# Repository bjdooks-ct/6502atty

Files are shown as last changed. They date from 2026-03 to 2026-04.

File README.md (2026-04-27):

# 6502 Atty

A 6502 SBC with an ATMega as a contoller and monitor for the 6502.

This is an initial commit as PCBs are off for manufacture and not been tested. This includes the prototype firmware and the first cut of the firmware code.

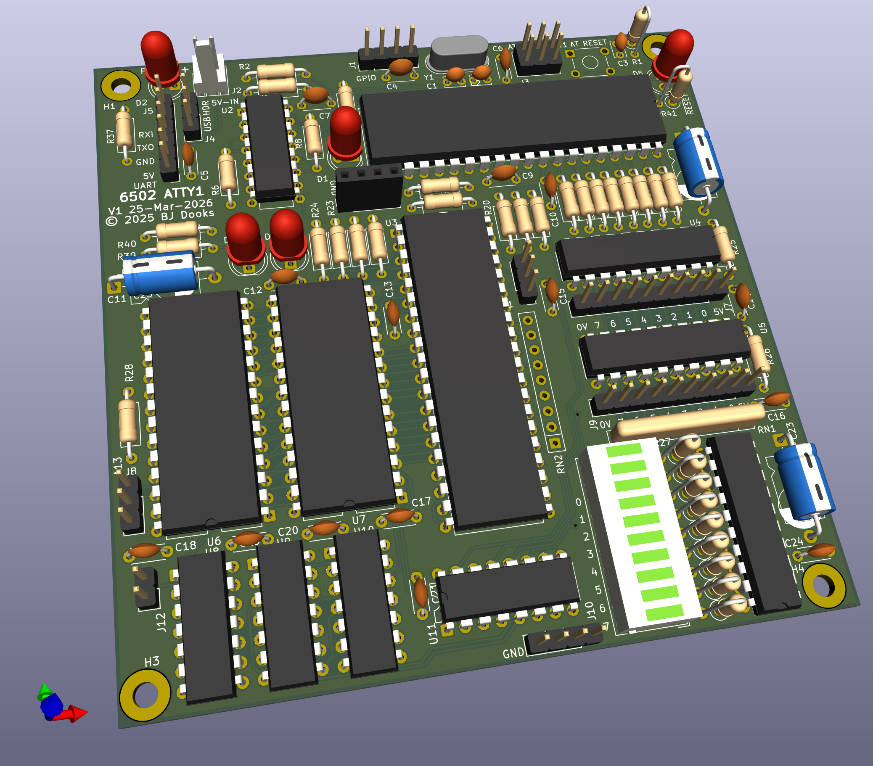
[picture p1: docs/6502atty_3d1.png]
3D PCB view


The ATmega is probably the easiest MCU to get and program which is 5V tolerant. The 1284P is the current choice as the smaller memory versions are not much cheaper.

There is now a [photo album](https://photos.app.goo.gl/qwDDgCh3WiyMoqd4A) of the build on my google photos.

The clock synchronisation logic is provided by U2A and U2B. U2B takes the PWM output from the ATMega and is used to both halve ti and make it a square wave. The /S input is used when the clock is high to stop any transition low (which would complete the 6502's cycle) which comes from the U2A flip-flop. U2A is triggered by an access to the ATMega and sets /CLOCK_STOP active to stop the 6502 clock until the /AT_ACK signal is active, resetting U2A and making /CLOCK_STOP inactive which then allows U2B to continue generating a clock for the 6502.

## Build notes for v1 rev1

- The 100UF capacitors are 16mm long so trying 47uF, layout change?

The LED resistors will probably need to be reduced to 680R or low as 506R depending on the LEDs being fitted.

The pull-up/pull-down resistors can be anywhere from 1K to 4K7, experiments with previous boards show 10K may not be suitable with certain variants of the 6052. Anything below 1K is probably going to have issues with current dissapation as that will be around 5mA per resistor. 

During test it was found that there seems to be a difference in operation dependong on how the PHi2 jumper is selected. If the PHI2O is used, we get proper operation but if CPU_CLK is seleted then the download code works but the code that is downloaded does not work.

## PCB updates (v1 rev2)

The updates for the second PCB revision are mostly bug-fixes and to make the board smaller to try and get to the 10x10cm point that JLCPCB and others use for cheaper services. There may be in future a version with a few bits of surface mount, like moving to one of the USB capable Atmel devices and adding a direct USB port.

- Added J12 to route ~WE signal to the PGM/~WE to allow SRAM
  - Also requires a R/!W signal gated with PHI2 high
  - Added R~{W}ph signal for ROM
  - This new signal could also drive RAM ~WE and connect ~CS to A15
- Connected ROM's VPP signal to GND, if using SRAM, ties A14 to GND
- U9C's pins 9 and 10 swapped for routing
- U11's E1/E2 pins swapped for easier routing
- Transcription error from prototype, ROM_ACC should be from AND not NAND gate
  - Swao U8C for one of U10 spare gates
- RDY line missing pull-up resistor
- 74LS573 replaced with 74LS574
  - 573 latches when Load is high, and our enable is low
  - 574 will load on rising edge of load pin, so should work
- Made PCB smaller, moved a few LEDs and things around to make this work
- Dropped 1K series drive resistor for the crystal
  - ATMega will not start if this resistor is there
- Serial converter is rotated 180deg to the actual unit
- Recomendation for AVRisp is to use 10K on ATMega's nRESET, so changed for now
  - See crystal series resistor notes.
- Added silkscreen with major part info to help with production

Currently unknown issues:
- Firmware only works with PHI2 jumper on PHI2out
  - can't see any scoped difference between CPUclk and PHI2out
  - possibly a rise-time on the clock with the 1K resistor in it

## PCB updates (v1 rev3)

This revision has minor updates for ease of assembly and a few minor annoyances over how the layout has come out, such as the mounting hole positions not being fully aligned.

The changes are:

- Made LEDs all the same orientation
  - also changed D2's resistor to be on ground side to make routing nicer
- Reduction in the x-size of the board by pushing control logic over
- Changed ROM A13 to solder pad, probably ok to just have A13 on this pin
- Used per-pin options on DIP to remove automatic ground ties
  - manually added a single ground tie to those pads
  - also made the keep-out a bit bigger to allow easier isolation cuts
- Made hole positions mostly consistent at edge of board
- Got down to 100x100mm dimensions with a more shuffling
- Added header and resistors for last two LEDs on bargrapth
  - Hesader J13 and two resistors to VCC for these
- Replaced input buffer U5 with 74x574
  - Added IOCLK from PHI2
  - Removed R26 as not needed
- could we use a 74x574 as input buffer too
  - if we tied ~OE and CP this would almost work, FF loaded on low-high
  - decided to bring PHI2 to the 74x574 to load state before read
  - device latches on low high and we need stable during the high clock phase
- Minor updats to clearand and island removal on the power planes

Processed the files and sent to JLCPCB, the manufacturing files commited in kicad/release3

To do for rev4:
- do we really need to have pull-ups on nmi/irq lines
  - atmega is always going to be needed unless you inject clk into gates

# Firmware

The firmware is currently in development. To build, you will need at-least avr-gcc and the relevant libraries and is currently only being tested on Linux (Debian). Once built, download to the ATMega using something like avrdude.

## Revision information

The original prototype version was built on a perfboard, and not released.

# Notes

Bee logo provided by Rob Kendrick

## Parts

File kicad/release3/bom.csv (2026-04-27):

Designator | Footprint | Quantity | Value | LCSC Part #
BAR1 | HDSP-4850 | 1 | HDSP-4850
C1, C2 | C_Disc_D3.4mm_W2.1mm_P2.50mm | 2 | 12pF
C10 | C_Disc_D4.3mm_W1.9mm_P5.00mm | 1 | ~
C11, C23, C8 | CP_Axial_L10.0mm_D6.0mm_P15.00mm_Horizontal | 3 | 100uF/16V
C12, C13, C14, C15, C16, C17, C18, C19, C20, C21, C24, C4, C5, C6, C7, C9 | C_Disc_D4.3mm_W1.9mm_P5.00mm | 16 | 100nF
C3 | C_Disc_D3.4mm_W2.1mm_P2.50mm | 1 | ?
D1 | LED_D5.0mm | 1 | LED_Small_Filled
D2, D3, D4, D5 | LED_D5.0mm | 4 | RED
J1, J10 | PinHeader_1x04_P2.54mm_Vertical | 2 | Conn_01x04_Pin
J11, J4 | PinHeader_1x03_P2.54mm_Vertical | 2 | Conn_01x03_Pin
J12, J13 | PinHeader_1x02_P2.54mm_Vertical | 2 | Conn_01x02_Pin
J2 | Molex_KK-254_AE-6410-02A_1x02_P2.54mm_Vertical | 1 | Conn_01x02_Pin
J3 | PinHeader_2x03_P2.54mm_Vertical | 1 | Conn_02x03_Odd_Even
J5 | PinHeader_1x06_P2.54mm_Vertical | 1 | Conn_01x06_Pin
J6 | PinSocket_1x04_P2.54mm_Vertical | 1 | Conn_01x04_Pin
J7, J9 | PinHeader_1x10_P2.54mm_Vertical | 2 | Conn_01x10_Pin
R1 | R_Axial_DIN0207_L6.3mm_D2.5mm_P2.54mm_Vertical | 1 | 10K
R10, R11, R12, R13, R14, R15, R16, R17 | R_Axial_DIN0207_L6.3mm_D2.5mm_P10.16mm_Horizontal | 8 | 330R
R18, R19, R20, R21, R22, R23, R25, R28, R6, R8, R9 | R_Axial_DIN0207_L6.3mm_D2.5mm_P10.16mm_Horizontal | 11 | 4K7
R2, R3, R37, R39, R40 | R_Axial_DIN0207_L6.3mm_D2.5mm_P10.16mm_Horizontal | 5 | 1K
R24 | R_Axial_DIN0207_L6.3mm_D2.5mm_P10.16mm_Horizontal | 1 | 560R
R27, R29, R30, R31, R32, R33, R34, R35, R36, R38 | R_Axial_DIN0207_L6.3mm_D2.5mm_P2.54mm_Vertical | 10 | 680R
R41, R5 | R_Axial_DIN0207_L6.3mm_D2.5mm_P2.54mm_Vertical | 2 | 1K
R42 | R_Axial_DIN0207_L6.3mm_D2.5mm_P10.16mm_Horizontal | 1 | R
RN1 | R_Array_SIP9 | 1 | 4K7
SW1 | SW_TH_Tactile_Omron_B3F-10xx | 1 | SW_Push
U1 | DIP-40_W15.24mm | 1 | ATmega164P-20P
U10 | DIP-14_W7.62mm | 1 | 74LS08
U11 | DIP-16_W7.62mm | 1 | 74LS138
U12, U13, U4 | DIP-20_W7.62mm | 3 | 74LS574
U2 | DIP-16_W7.62mm | 1 | 74LS112
U3 | DIP-40_W15.24mm | 1 | W65C02SxP
U6 | DIP-28_W15.24mm | 1 | 27C128
U7 | DIP-28_W15.24mm | 1 | KM62256CLP
U8, U9 | DIP-14_W7.62mm | 2 | 74LS00
Y1 | Crystal_HC49-4H_Vertical | 1 | 18.432MHz

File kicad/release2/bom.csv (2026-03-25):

Designator | Footprint | Quantity | Value | LCSC Part #
BAR1 | HDSP-4850 | 1 | HDSP-4850
C1, C2 | C_Disc_D3.4mm_W2.1mm_P2.50mm | 2 | 12pF
C10 | C_Disc_D4.3mm_W1.9mm_P5.00mm | 1 | ~
C11, C23, C8 | CP_Axial_L10.0mm_D6.0mm_P15.00mm_Horizontal | 3 | 100uF/16V
C12, C13, C14, C15, C16, C17, C18, C19, C20, C21, C24, C4, C5, C6, C7, C9 | C_Disc_D4.3mm_W1.9mm_P5.00mm | 16 | 100nF
C3 | C_Disc_D3.4mm_W2.1mm_P2.50mm | 1 | ?
D1 | LED_D5.0mm | 1 | LED_Small_Filled
D2, D3, D4, D5 | LED_D5.0mm | 4 | RED
J1, J10 | PinHeader_1x04_P2.54mm_Vertical | 2 | Conn_01x04_Pin
J11, J4, J8 | PinHeader_1x03_P2.54mm_Vertical | 3 | Conn_01x03_Pin
J12 | PinHeader_1x02_P2.54mm_Vertical | 1 | Conn_01x02_Pin
J2 | Molex_KK-254_AE-6410-02A_1x02_P2.54mm_Vertical | 1 | Conn_01x02_Pin
J3 | PinHeader_2x03_P2.54mm_Vertical | 1 | Conn_02x03_Odd_Even
J5 | PinHeader_1x06_P2.54mm_Vertical | 1 | Conn_01x06_Pin
J6 | PinSocket_1x04_P2.54mm_Vertical | 1 | Conn_01x04_Pin
J7, J9 | PinHeader_1x10_P2.54mm_Vertical | 2 | Conn_01x10_Pin
R1 | R_Axial_DIN0207_L6.3mm_D2.5mm_P2.54mm_Vertical | 1 | 10K
R10, R11, R12, R13, R14, R15, R16, R17 | R_Axial_DIN0207_L6.3mm_D2.5mm_P10.16mm_Horizontal | 8 | 330R
R18, R19, R20, R21, R22, R23, R25, R26, R28, R6, R8, R9 | R_Axial_DIN0207_L6.3mm_D2.5mm_P10.16mm_Horizontal | 12 | 4K7
R2, R3, R37, R39, R40, R5 | R_Axial_DIN0207_L6.3mm_D2.5mm_P10.16mm_Horizontal | 6 | 1K
R24 | R_Axial_DIN0207_L6.3mm_D2.5mm_P10.16mm_Horizontal | 1 | 560R
R27, R29, R30, R31, R32, R33, R34, R35, R38 | R_Axial_DIN0207_L6.3mm_D2.5mm_P2.54mm_Vertical | 9 | 680R
R41 | R_Axial_DIN0207_L6.3mm_D2.5mm_P2.54mm_Vertical | 1 | 1K
R42 | R_Axial_DIN0207_L6.3mm_D2.5mm_P10.16mm_Horizontal | 1 | R
RN1 | R_Array_SIP9 | 1 | R_Network08
SW1 | SW_TH_Tactile_Omron_B3F-10xx | 1 | SW_Push
U1 | DIP-40_W15.24mm | 1 | ATmega164P-20P
U10 | DIP-14_W7.62mm | 1 | 74LS08
U11 | DIP-16_W7.62mm | 1 | 74LS138
U12, U4 | DIP-20_W7.62mm | 2 | 74LS574
U2 | DIP-16_W7.62mm | 1 | 74LS112
U3 | DIP-40_W15.24mm | 1 | W65C02SxP
U5 | DIP-20_W7.62mm | 1 | 74HC245
U6 | DIP-28_W15.24mm | 1 | 27C128
U7 | DIP-28_W15.24mm | 1 | KM62256CLP
U8, U9 | DIP-14_W7.62mm | 2 | 74LS00
Y1 | Crystal_HC49-4H_Vertical | 1 | 18.432MHz

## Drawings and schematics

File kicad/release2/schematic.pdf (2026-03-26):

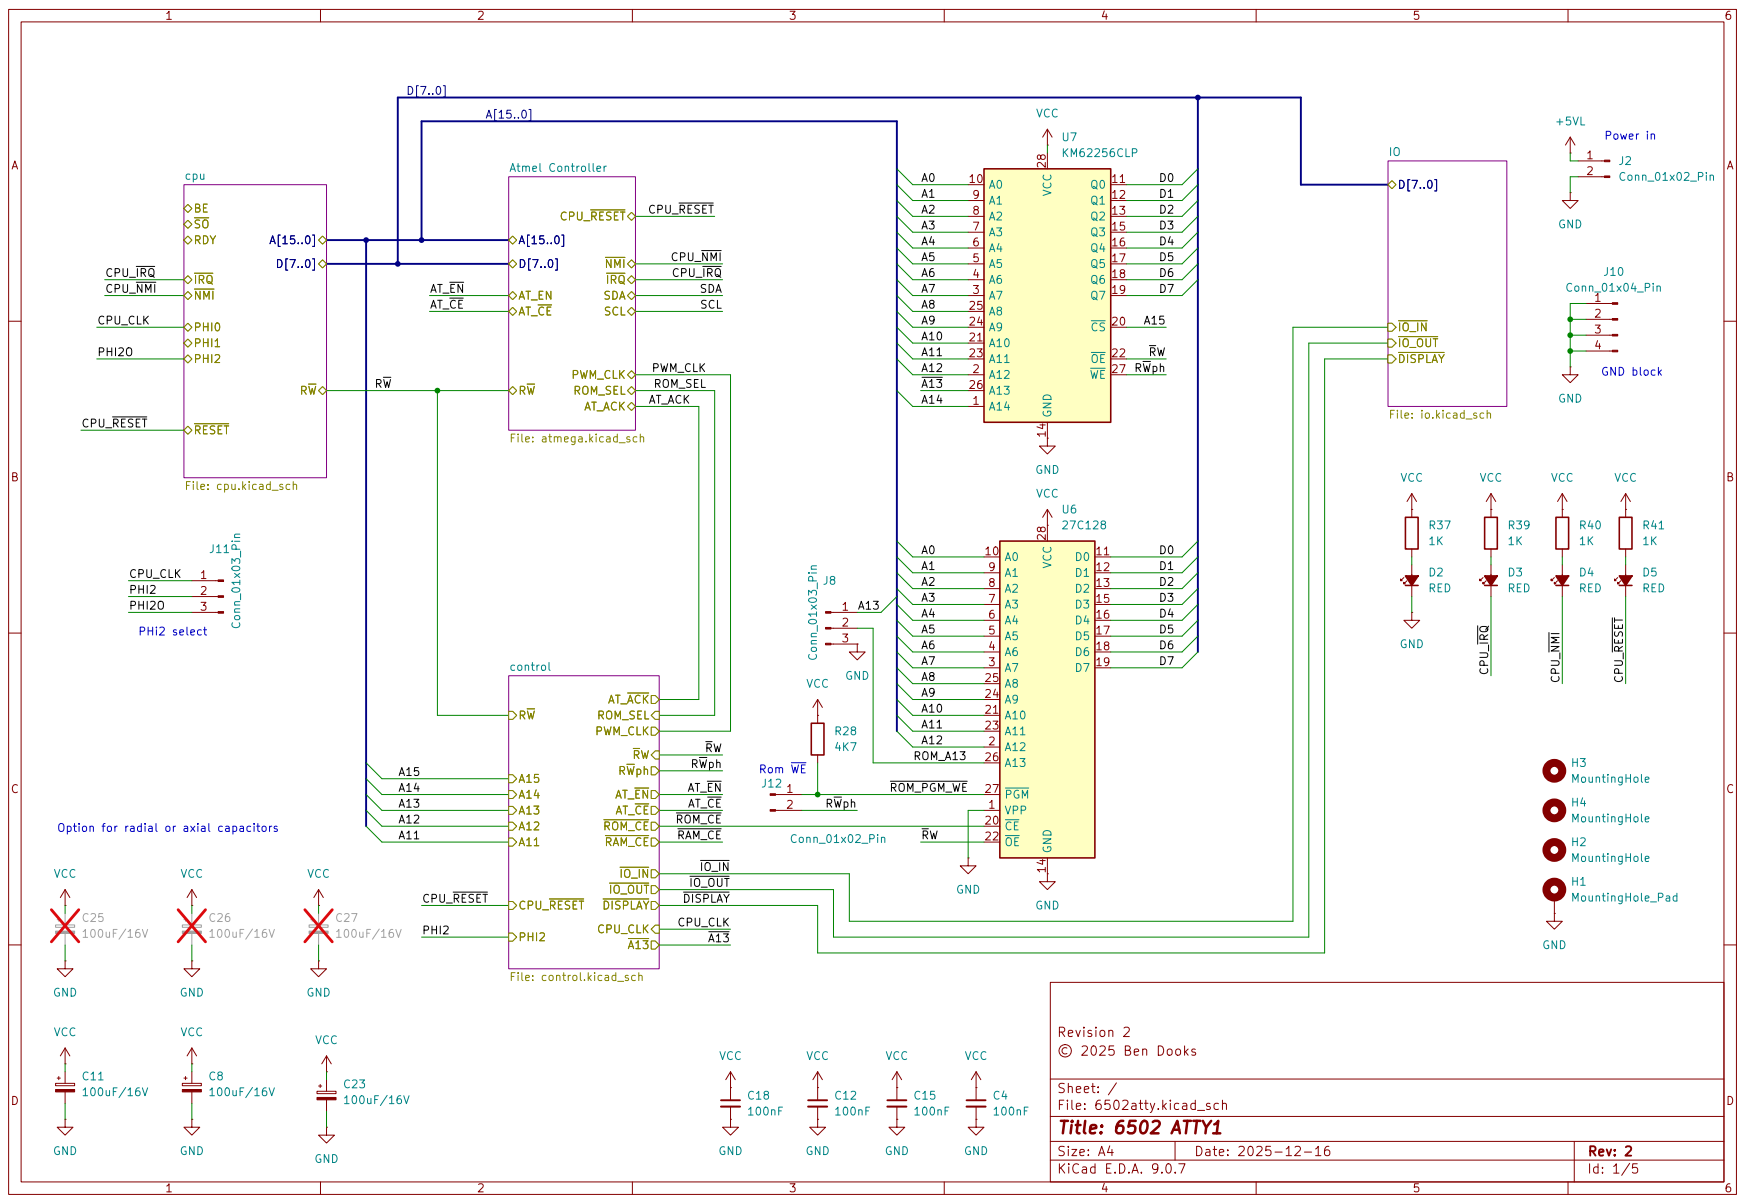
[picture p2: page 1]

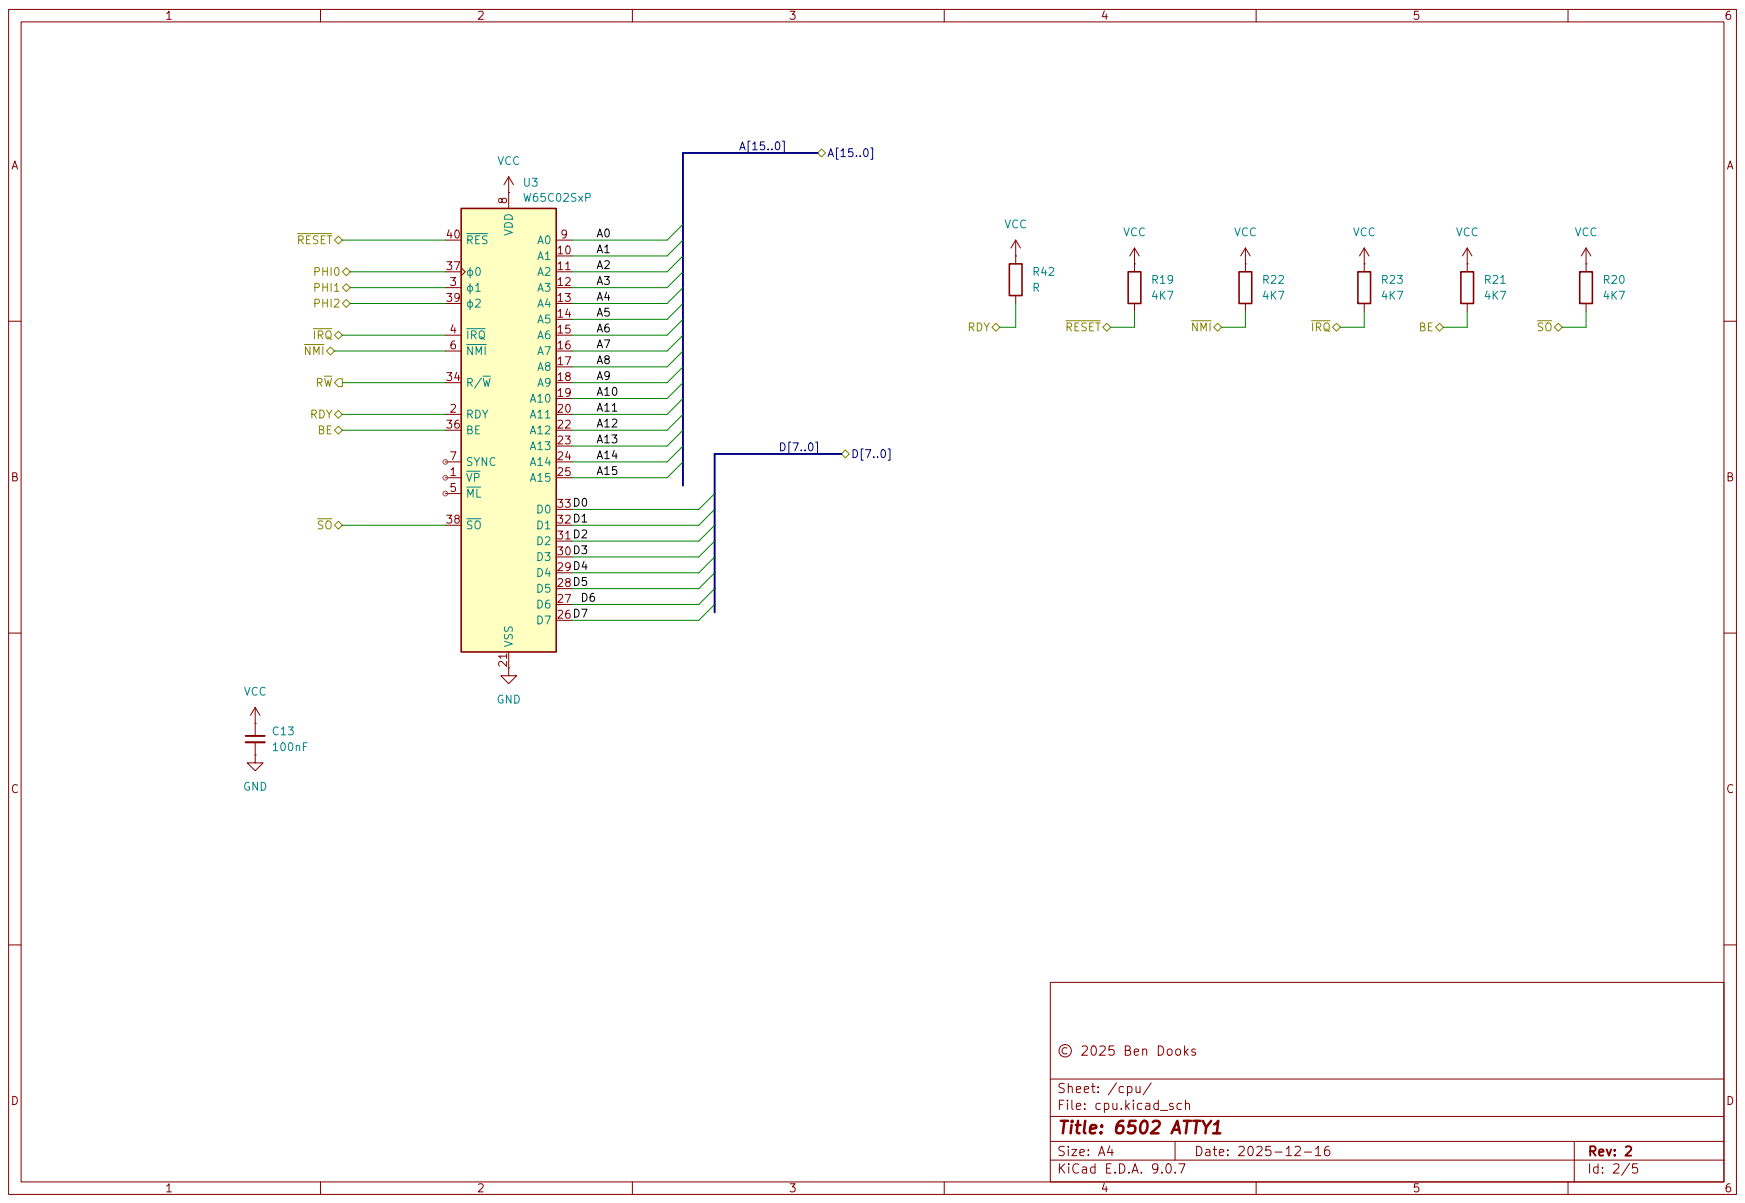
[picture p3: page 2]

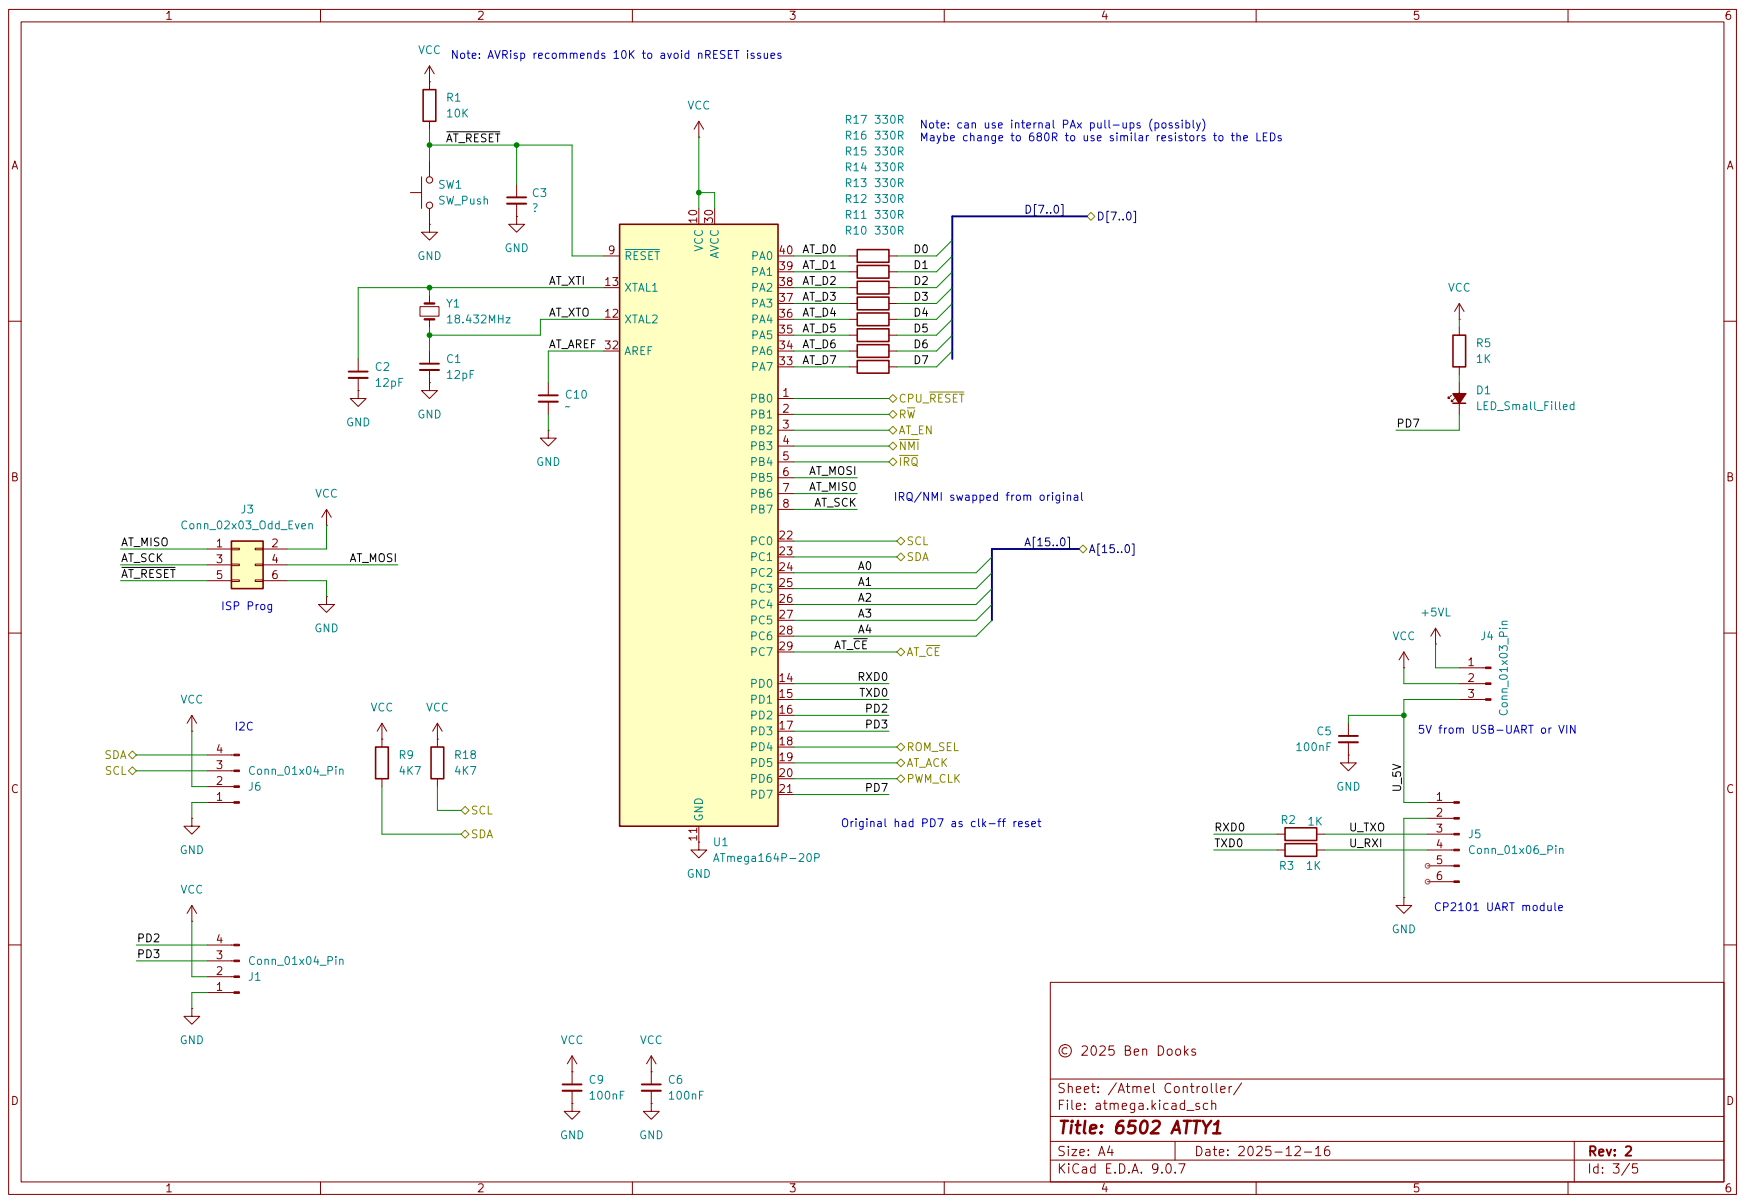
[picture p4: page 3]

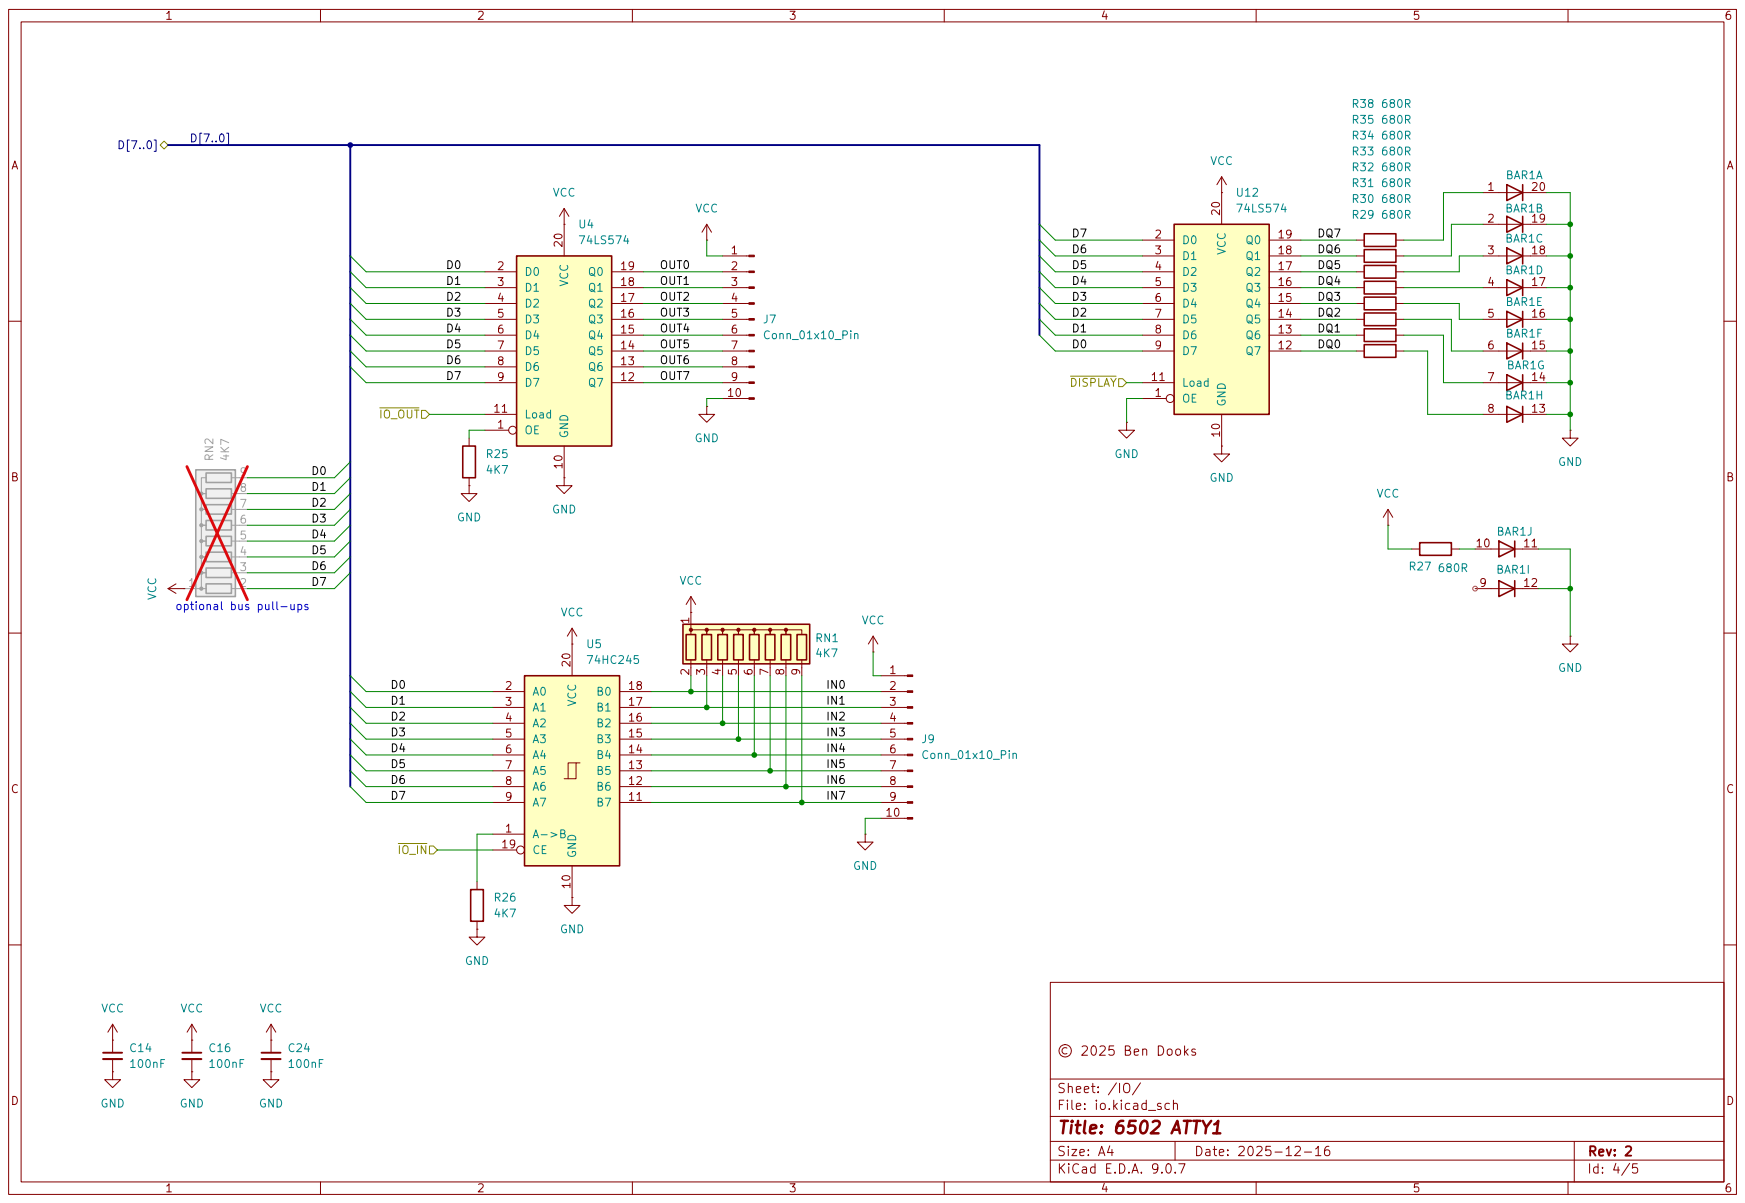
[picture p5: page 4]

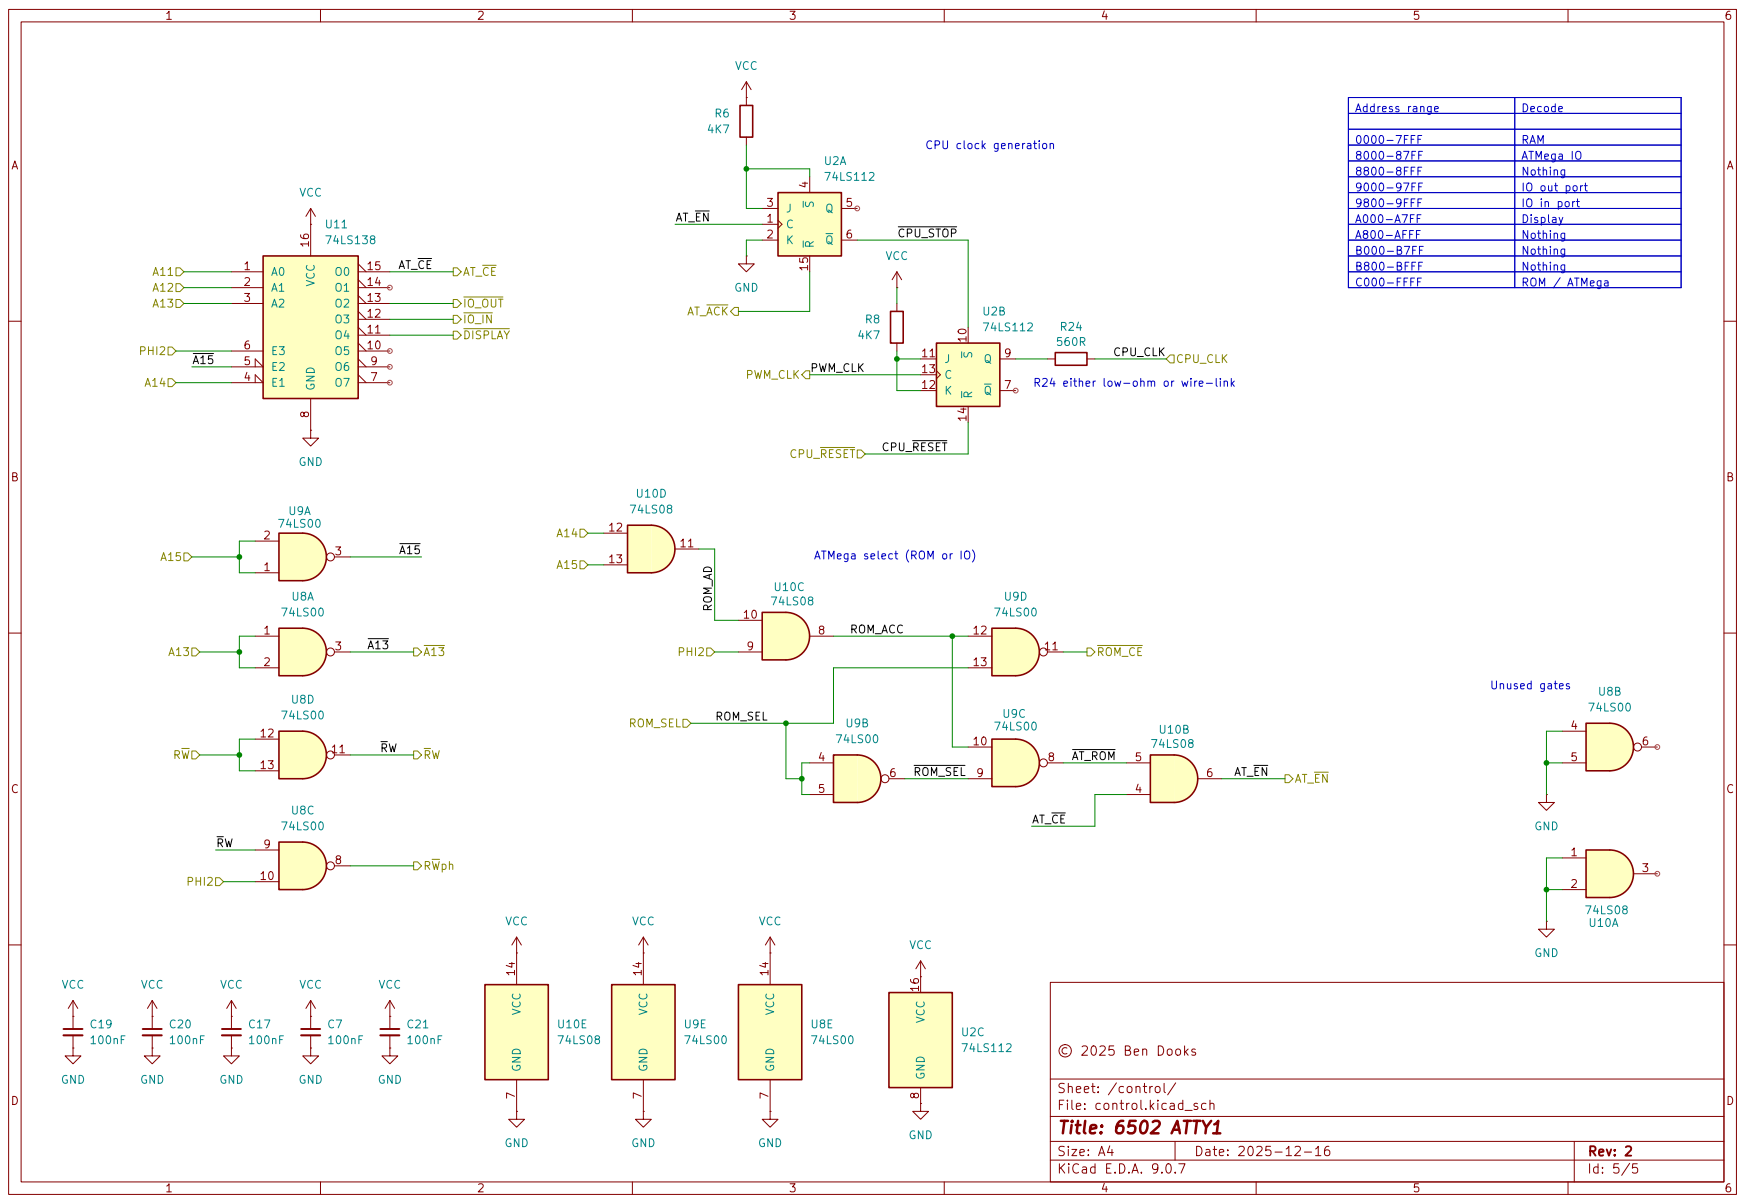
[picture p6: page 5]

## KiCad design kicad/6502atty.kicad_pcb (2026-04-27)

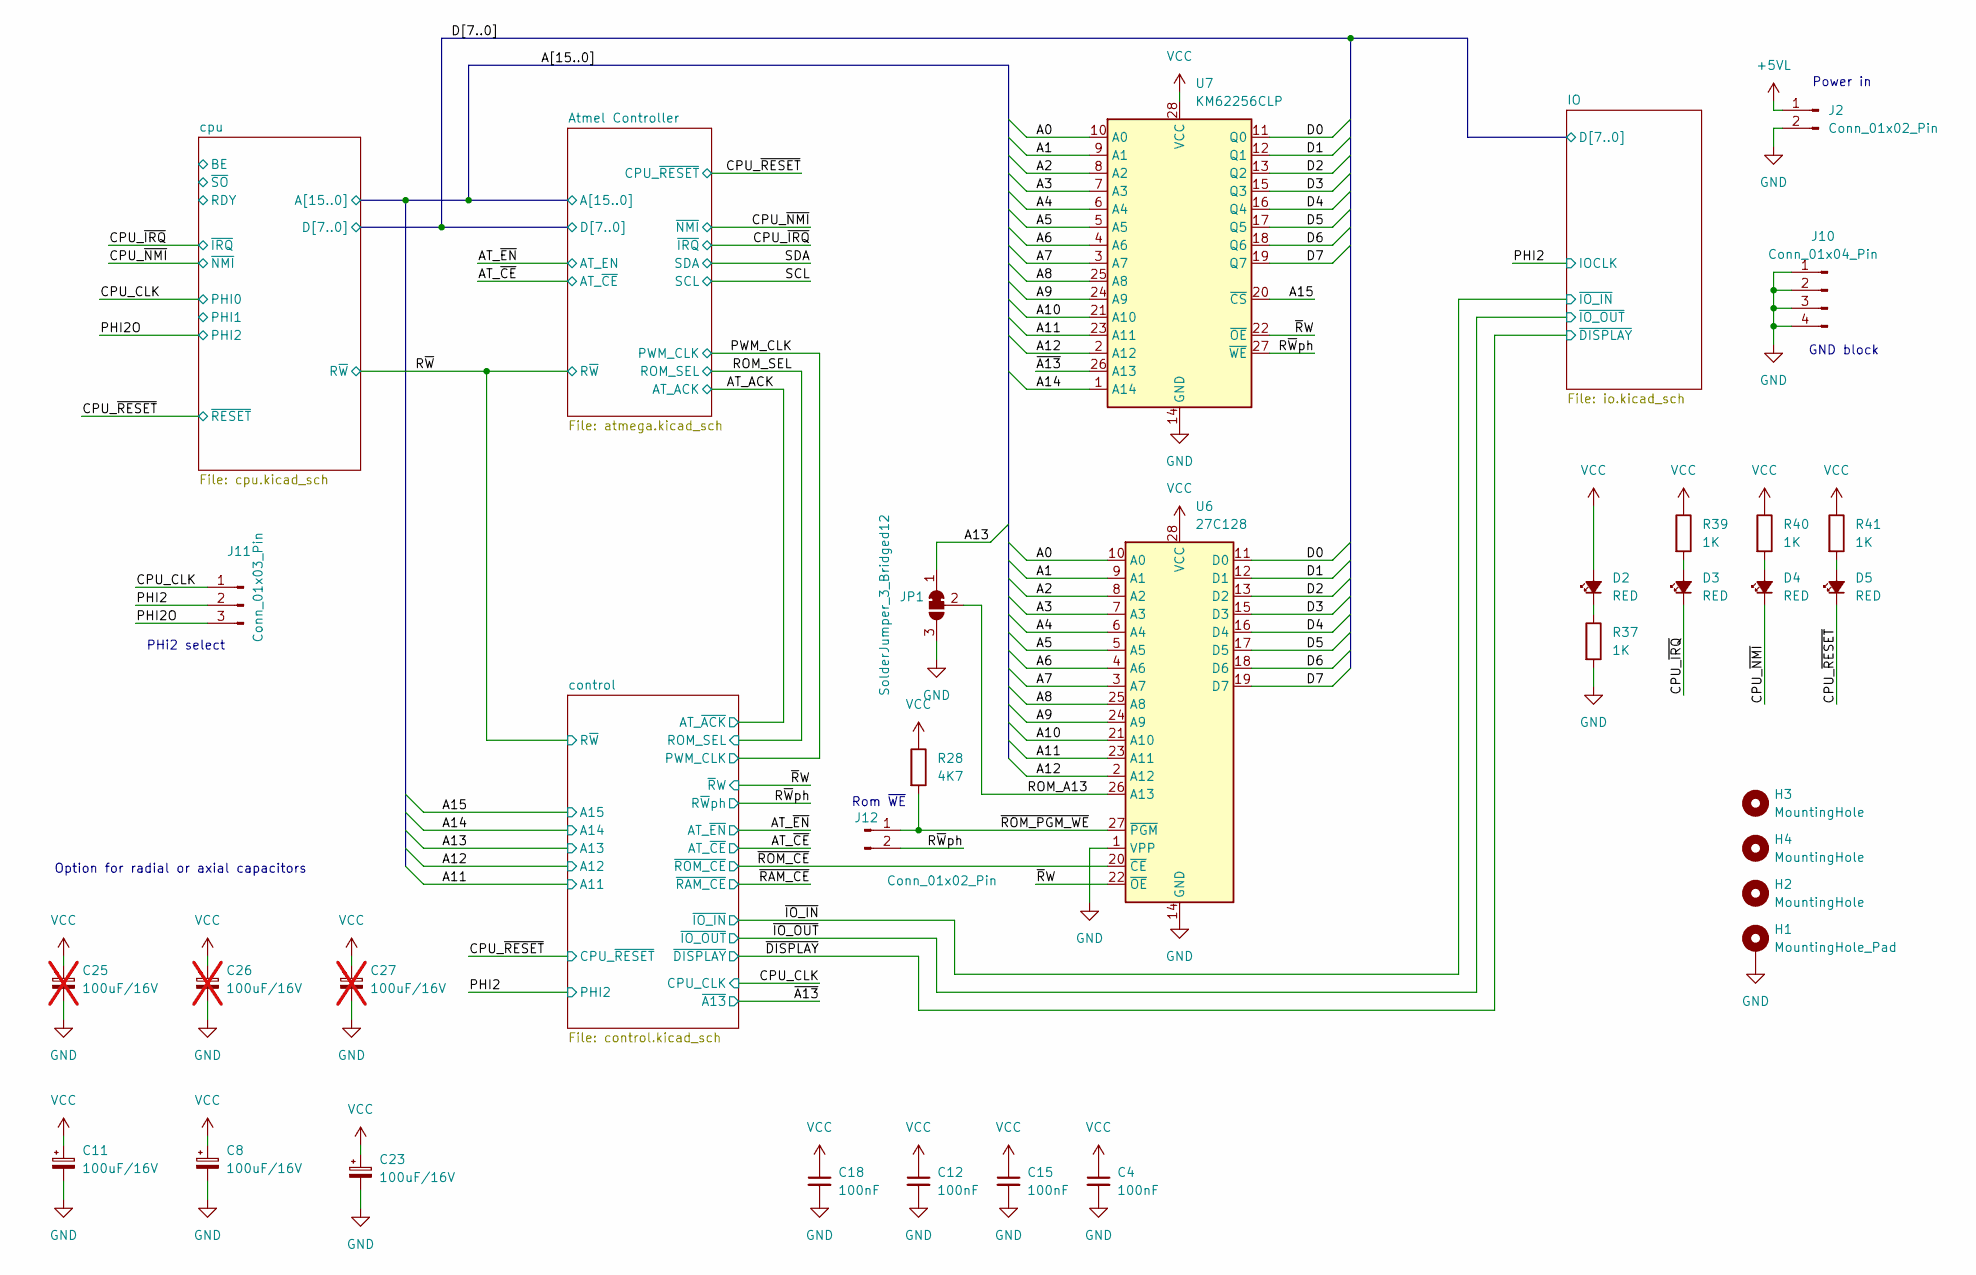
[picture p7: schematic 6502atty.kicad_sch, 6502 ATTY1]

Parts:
C4, C12, C15, C18: 100nF; C_Disc_D4.3mm_W1.9mm_P5.00mm
C8, C11, C23: 100uF/16V; CP_Axial_L10.0mm_D6.0mm_P15.00mm_Horizontal
C25, C26, C27: 100uF/16V; CP_Radial_D6.3mm_P2.50mm; not fitted
D2, D3, D4, D5: RED; LED_D5.0mm
H1: MountingHole_Pad; MountingHole_3.2mm_M3_Pad
H2, H3, H4: MountingHole; MountingHole_3.2mm_M3_Pad
J2: Conn_01x02_Pin; Molex_KK-254_AE-6410-02A_1x02_P2.54mm_Vertical
J10: Conn_01x04_Pin; PinHeader_1x04_P2.54mm_Vertical
J11: Conn_01x03_Pin; PinHeader_1x03_P2.54mm_Vertical
J12: Conn_01x02_Pin; PinHeader_1x02_P2.54mm_Vertical
JP1: SolderJumper_3_Bridged12; SolderJumper-3_P1.3mm_Bridged12_Pad1.0x1.5mm_NumberLabels
R28: 4K7; R_Axial_DIN0207_L6.3mm_D2.5mm_P10.16mm_Horizontal
R37, R39, R40: 1K; R_Axial_DIN0207_L6.3mm_D2.5mm_P10.16mm_Horizontal
R41: 1K; R_Axial_DIN0207_L6.3mm_D2.5mm_P2.54mm_Vertical
U6: 27C128; DIP-28_W15.24mm
U7: KM62256CLP; DIP-28_W15.24mm

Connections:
+5VL: J2.1; also elsewhere on the board
/A0: U6.10 (A0), U7.10 (A0); also elsewhere on the board
/A1: U6.9 (A1), U7.9 (A1); also elsewhere on the board
/A2: U6.8 (A2), U7.8 (A2); also elsewhere on the board
/A3: U6.7 (A3), U7.7 (A3); also elsewhere on the board
/A4: U6.6 (A4), U7.6 (A4); also elsewhere on the board
/A5: U6.5 (A5), U7.5 (A5); also elsewhere on the board
/A6: U6.4 (A6), U7.4 (A6); also elsewhere on the board
/A7: U6.3 (A7), U7.3 (A7); also elsewhere on the board
/A8: U6.25 (A8), U7.25 (A8); also elsewhere on the board
/A9: U6.24 (A9), U7.24 (A9); also elsewhere on the board
/A10: U6.21 (A10), U7.21 (A10); also elsewhere on the board
/A11: U6.23 (A11), U7.23 (A11); also elsewhere on the board
/A12: U6.2 (A12), U7.2 (A12); also elsewhere on the board
/A13: JP1.1 (A); also elsewhere on the board
/A14: U7.1 (A14); also elsewhere on the board
/A15: U7.20 (~CS); also elsewhere on the board
/CPU_CLK: J11.1; also elsewhere on the board
/CPU_~IRQ: D3.1 (K); also elsewhere on the board
/CPU_~NMI: D4.1 (K); also elsewhere on the board
/CPU_~RESET: D5.1 (K); also elsewhere on the board
/D0: U6.11 (D0), U7.11 (Q0); also elsewhere on the board
/D1: U6.12 (D1), U7.12 (Q1); also elsewhere on the board
/D2: U6.13 (D2), U7.13 (Q2); also elsewhere on the board
/D3: U6.15 (D3), U7.15 (Q3); also elsewhere on the board
/D4: U6.16 (D4), U7.16 (Q4); also elsewhere on the board
/D5: U6.17 (D5), U7.17 (Q5); also elsewhere on the board
/D6: U6.18 (D6), U7.18 (Q6); also elsewhere on the board
/D7: U6.19 (D7), U7.19 (Q7); also elsewhere on the board
/PHI2: J11.2; also elsewhere on the board
/PHI2O: J11.3; also elsewhere on the board
/ROM_A13: JP1.2 (C), U6.26 (A13)
/R~Wph: J12.2, U7.27 (~WE); also elsewhere on the board
/~A13: U7.26 (A13); also elsewhere on the board
/~ROM_CE: U6.20 (~CE); also elsewhere on the board
/~ROM_PGM_WE: J12.1, R28.2, U6.27 (~PGM)
/~RW: U6.22 (~OE), U7.22 (~OE); also elsewhere on the board
GND: C4.2, C8.2, C11.2, C12.2, C15.2, C18.2, C23.2, C25.2, C26.2, C27.2, H1.1 (1_1), J2.2, J10.1, J10.2, J10.3, J10.4, JP1.3 (B), R37.2, U6.1 (VPP), U6.14 (GND), U7.14 (GND); also elsewhere on the board
unnamed: D2.1 (K), R37.1
unnamed: D3.2 (A), R39.2
unnamed: D4.2 (A), R40.2
unnamed: D5.2 (A), R41.2
VCC: C4.1, C8.1, C11.1, C12.1, C15.1, C18.1, C23.1, C25.1, C26.1, C27.1, D2.2 (A), R28.1, R39.1, R40.1, R41.1, U6.28 (VCC), U7.28 (VCC); also elsewhere on the board

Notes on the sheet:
Power in
GND block
Option for radial or axial capacitors
PHi2 select
Rom ~{WE}

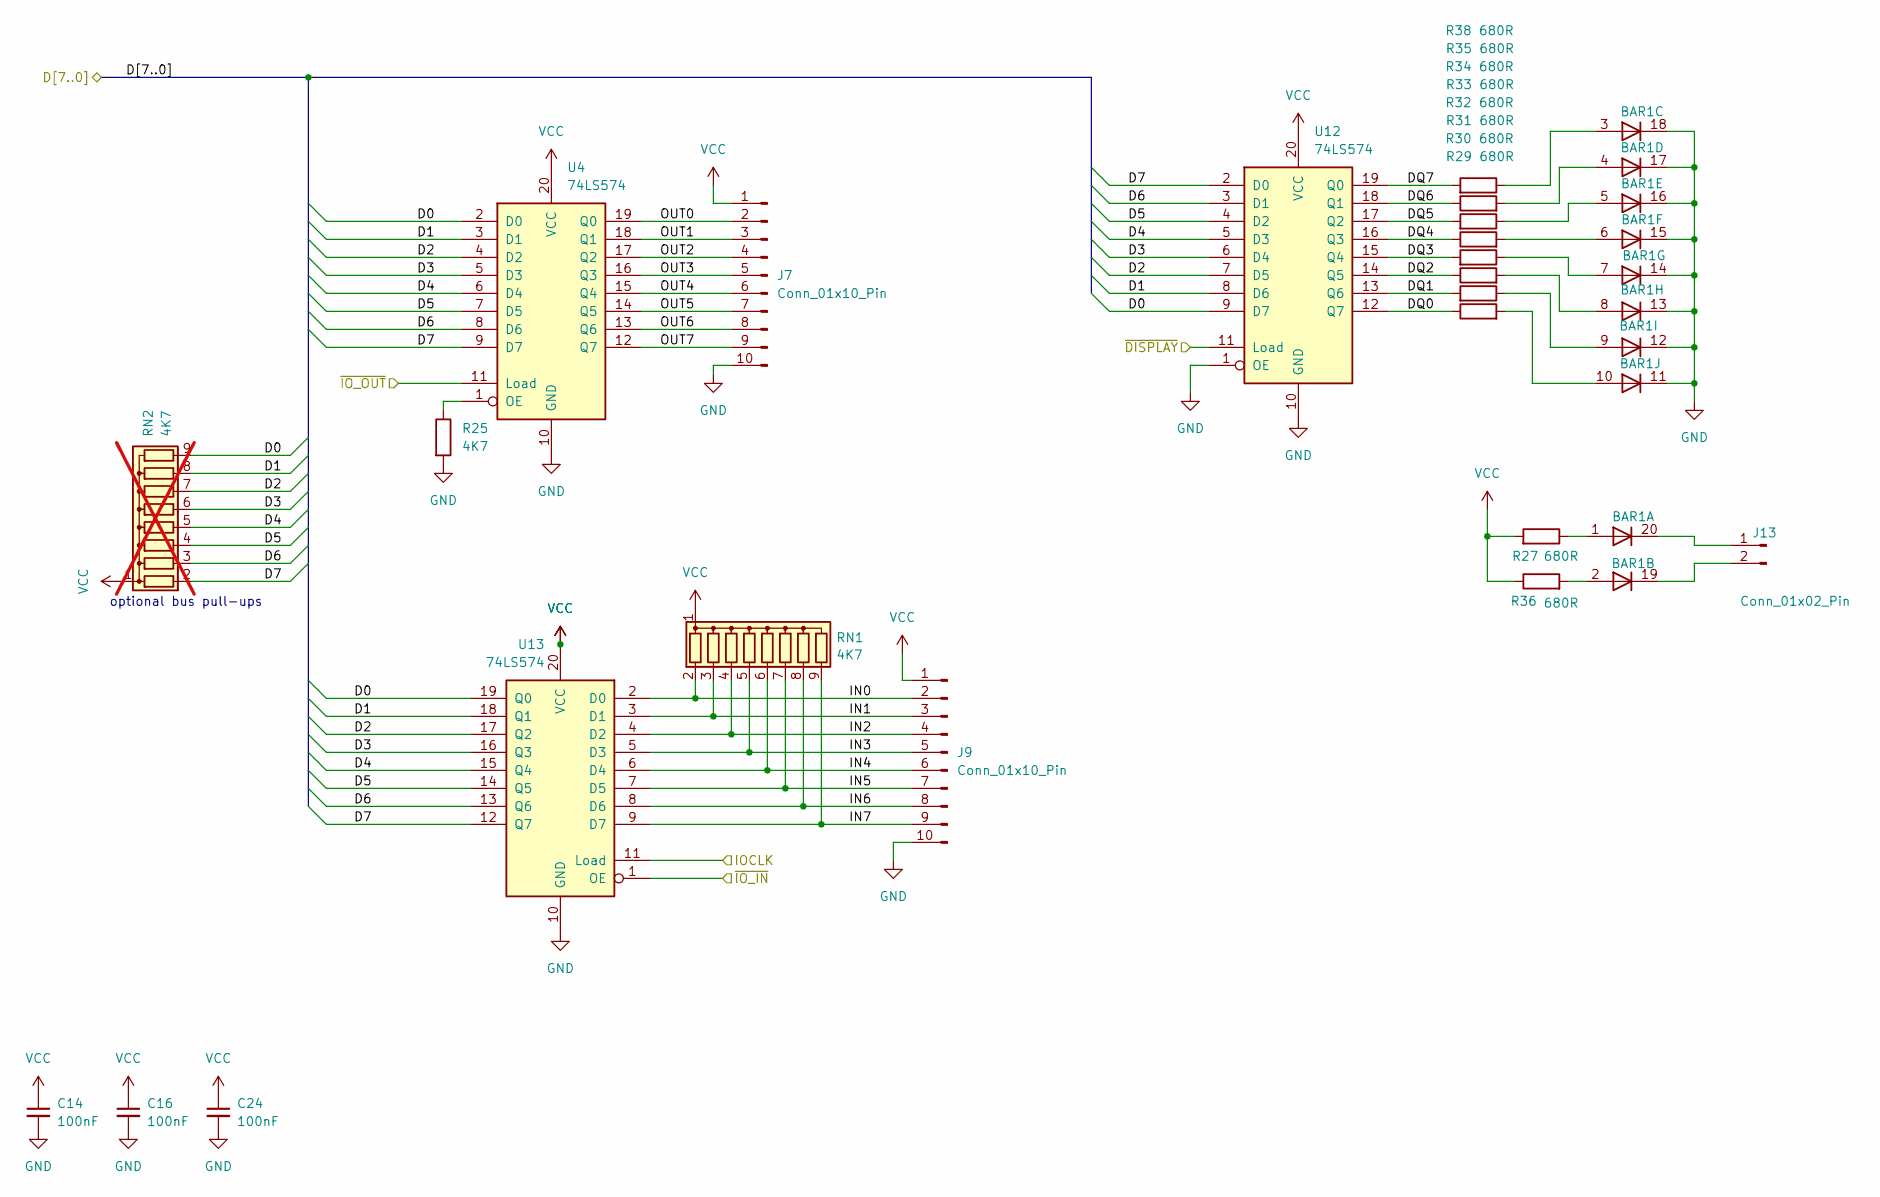
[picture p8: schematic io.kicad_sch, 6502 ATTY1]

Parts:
BAR1: HDSP-4850
C14, C16, C24: 100nF; C_Disc_D4.3mm_W1.9mm_P5.00mm
J7, J9: Conn_01x10_Pin; PinHeader_1x10_P2.54mm_Vertical
J13: Conn_01x02_Pin; PinHeader_1x02_P2.54mm_Vertical
R25: 4K7; R_Axial_DIN0207_L6.3mm_D2.5mm_P10.16mm_Horizontal
R27, R29, R30, R31, R32, R33, R34, R35, R36, R38: 680R; R_Axial_DIN0207_L6.3mm_D2.5mm_P2.54mm_Vertical
RN1: 4K7; R_Array_SIP9
RN2: 4K7; R_Array_SIP9; not fitted
U4, U12, U13: 74LS574; DIP-20_W7.62mm

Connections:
/D0: RN2.9 (R8), U4.2 (D0), U12.9 (D7), U13.19 (Q0); also elsewhere on the board
/D1: RN2.8 (R7), U4.3 (D1), U12.8 (D6), U13.18 (Q1); also elsewhere on the board
/D2: RN2.7 (R6), U4.4 (D2), U12.7 (D5), U13.17 (Q2); also elsewhere on the board
/D3: RN2.6 (R5), U4.5 (D3), U12.6 (D4), U13.16 (Q3); also elsewhere on the board
/D4: RN2.5 (R4), U4.6 (D4), U12.5 (D3), U13.15 (Q4); also elsewhere on the board
/D5: RN2.4 (R3), U4.7 (D5), U12.4 (D2), U13.14 (Q5); also elsewhere on the board
/D6: RN2.3 (R2), U4.8 (D6), U12.3 (D1), U13.13 (Q6); also elsewhere on the board
/D7: RN2.2 (R1), U4.9 (D7), U12.2 (D0), U13.12 (Q7); also elsewhere on the board
/IO/DQ0: R29.1, U12.12 (Q7)
/IO/DQ1: R30.2, U12.13 (Q6)
/IO/DQ2: R31.1, U12.14 (Q5)
/IO/DQ3: R32.2, U12.15 (Q4)
/IO/DQ4: R33.1, U12.16 (Q3)
/IO/DQ5: R34.2, U12.17 (Q2)
/IO/DQ6: R35.1, U12.18 (Q1)
/IO/DQ7: R38.2, U12.19 (Q0)
/IO/IN0: J9.2, RN1.2 (R1), U13.2 (D0)
/IO/IN1: J9.3, RN1.3 (R2), U13.3 (D1)
/IO/IN2: J9.4, RN1.4 (R3), U13.4 (D2)
/IO/IN3: J9.5, RN1.5 (R4), U13.5 (D3)
/IO/IN4: J9.6, RN1.6 (R5), U13.6 (D4)
/IO/IN5: J9.7, RN1.7 (R6), U13.7 (D5)
/IO/IN6: J9.8, RN1.8 (R7), U13.8 (D6)
/IO/IN7: J9.9, RN1.9 (R8), U13.9 (D7)
/IO/OUT0: J7.2, U4.19 (Q0)
/IO/OUT1: J7.3, U4.18 (Q1)
/IO/OUT2: J7.4, U4.17 (Q2)
/IO/OUT3: J7.5, U4.16 (Q3)
/IO/OUT4: J7.6, U4.15 (Q4)
/IO/OUT5: J7.7, U4.14 (Q5)
/IO/OUT6: J7.8, U4.13 (Q6)
/IO/OUT7: J7.9, U4.12 (Q7)
/PHI2: U13.11 (Load); also elsewhere on the board
/~DISPLAY: U12.11 (Load); also elsewhere on the board
/~IO_IN: U13.1 (OE); also elsewhere on the board
/~IO_OUT: U4.11 (Load); also elsewhere on the board
GND: BAR1.11 (K), BAR1.12 (K), BAR1.13 (K), BAR1.14 (K), BAR1.15 (K), BAR1.16 (K), BAR1.17 (K), BAR1.18 (K), C14.2, C16.2, C24.2, J7.10, J9.10, R25.2, U4.10 (GND), U12.1 (OE), U12.10 (GND), U13.10 (GND); also elsewhere on the board
unnamed: BAR1.1 (A), R27.1
unnamed: BAR1.20 (K), J13.1
unnamed: BAR1.2 (A), R36.2
unnamed: BAR1.19 (K), J13.2
unnamed: BAR1.3 (A), R38.1
unnamed: BAR1.4 (A), R35.2
unnamed: BAR1.5 (A), R34.1
unnamed: BAR1.6 (A), R33.2
unnamed: BAR1.7 (A), R32.1
unnamed: BAR1.8 (A), R31.2
unnamed: BAR1.9 (A), R30.1
unnamed: BAR1.10 (A), R29.2
unnamed: R25.1, U4.1 (OE)
VCC: C14.1, C16.1, C24.1, J7.1, J9.1, R27.2, R36.1, RN1.1 (common), RN2.1 (common), U4.20 (VCC), U12.20 (VCC), U13.20 (VCC); also elsewhere on the board

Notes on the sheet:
optional bus pull-ups

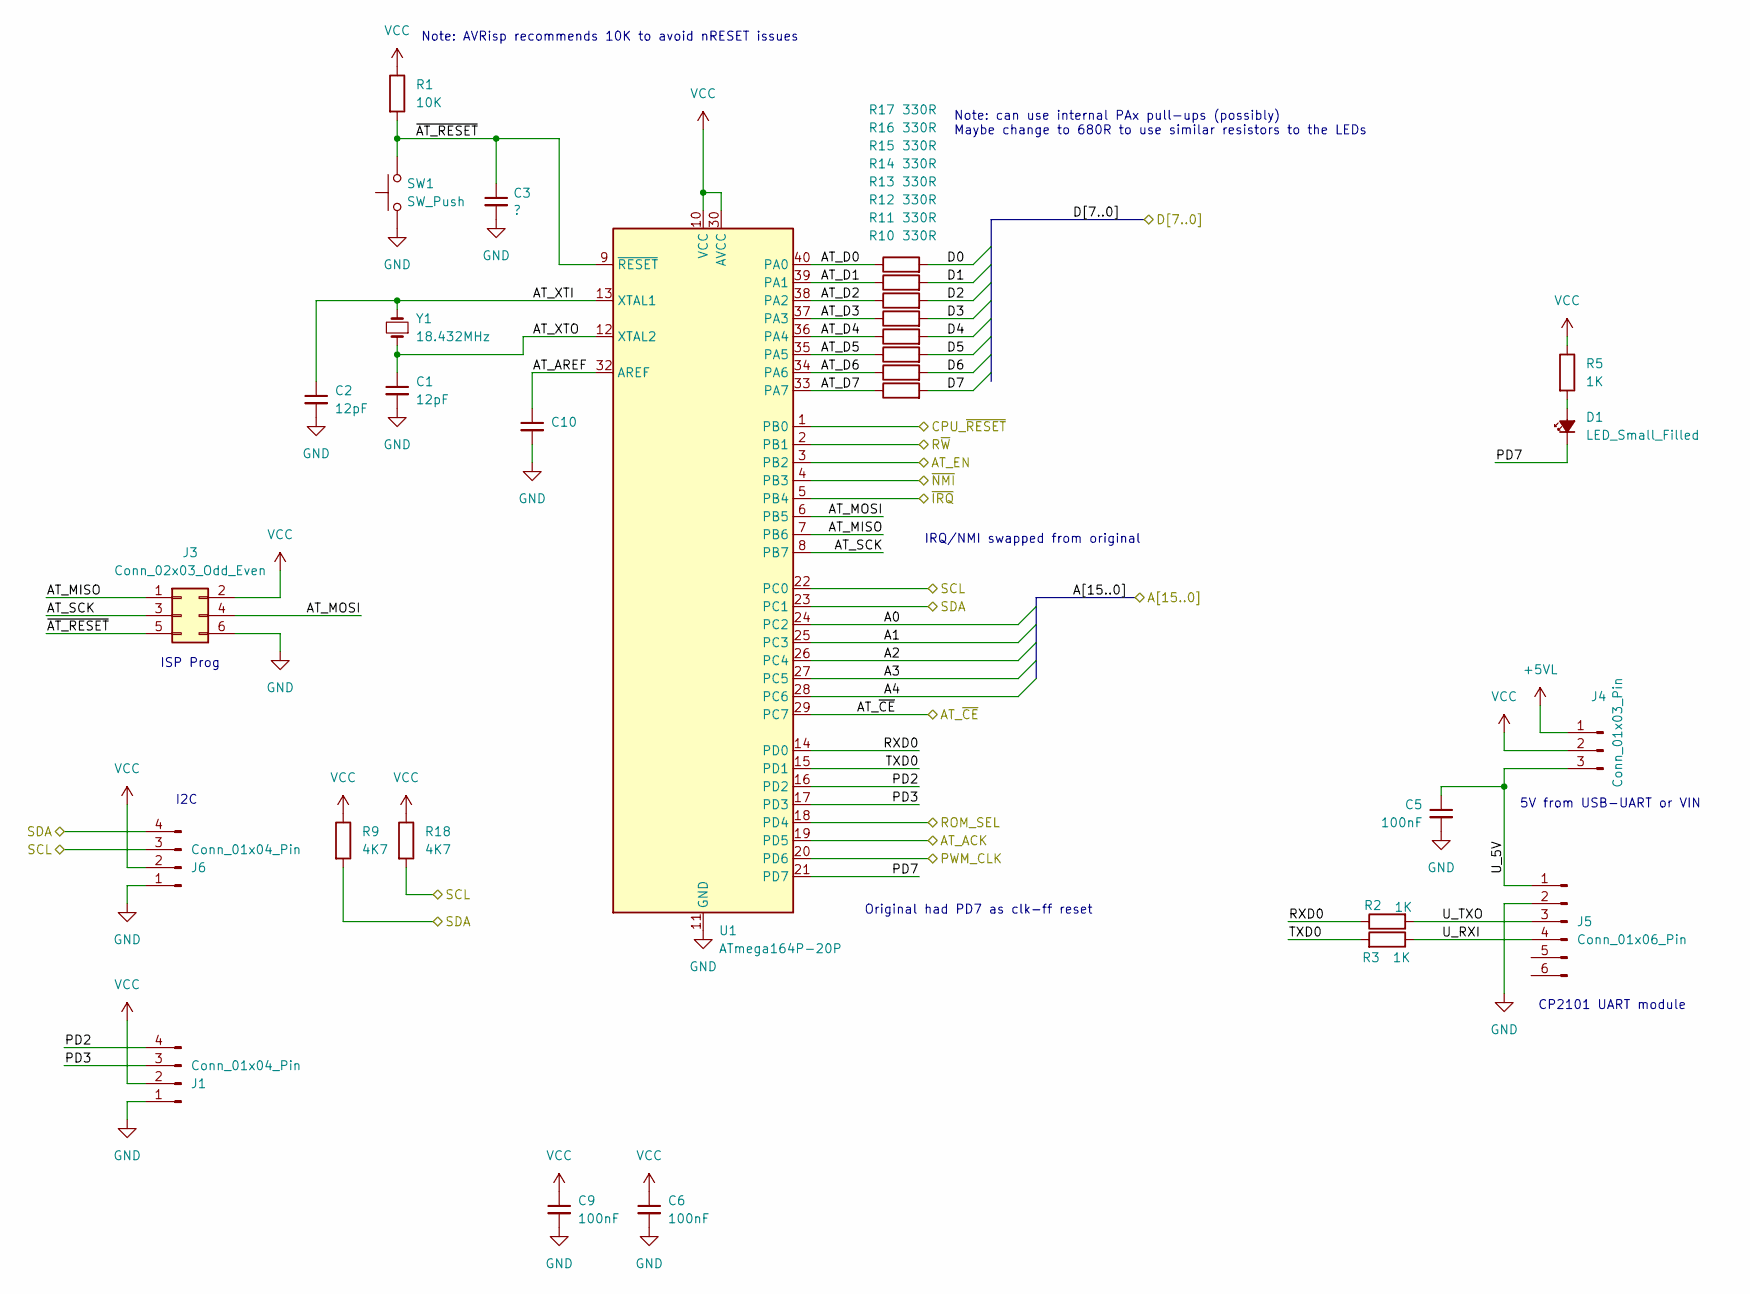
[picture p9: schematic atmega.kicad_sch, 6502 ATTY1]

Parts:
C1, C2: 12pF; C_Disc_D3.4mm_W2.1mm_P2.50mm
C3: ?; C_Disc_D3.4mm_W2.1mm_P2.50mm
C5, C6, C9: 100nF; C_Disc_D4.3mm_W1.9mm_P5.00mm
C10: C_Disc_D4.3mm_W1.9mm_P5.00mm
D1: LED_Small_Filled; LED_D5.0mm
J1: Conn_01x04_Pin; PinHeader_1x04_P2.54mm_Vertical
J3: Conn_02x03_Odd_Even; PinHeader_2x03_P2.54mm_Vertical
J4: Conn_01x03_Pin; PinHeader_1x03_P2.54mm_Vertical
J5: Conn_01x06_Pin; PinHeader_1x06_P2.54mm_Vertical
J6: Conn_01x04_Pin; PinSocket_1x04_P2.54mm_Vertical
R1: 10K; R_Axial_DIN0207_L6.3mm_D2.5mm_P2.54mm_Vertical
R2, R3: 1K; R_Axial_DIN0207_L6.3mm_D2.5mm_P10.16mm_Horizontal
R5: 1K; R_Axial_DIN0207_L6.3mm_D2.5mm_P2.54mm_Vertical
R9, R18: 4K7; R_Axial_DIN0207_L6.3mm_D2.5mm_P10.16mm_Horizontal
R10, R11, R12, R13, R14, R15, R16, R17: 330R; R_Axial_DIN0207_L6.3mm_D2.5mm_P10.16mm_Horizontal
SW1: SW_Push; SW_TH_Tactile_Omron_B3F-10xx
U1: ATmega164P-20P; DIP-40_W15.24mm
Y1: 18.432MHz; Crystal_HC49-4H_Vertical

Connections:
+5VL: J4.1; also elsewhere on the board
/A0: U1.24 (PC2); also elsewhere on the board
/A1: U1.25 (PC3); also elsewhere on the board
/A2: U1.26 (PC4); also elsewhere on the board
/A3: U1.27 (PC5); also elsewhere on the board
/A4: U1.28 (PC6); also elsewhere on the board
/AT_ACK: U1.19 (PD5); also elsewhere on the board
/AT_~CE: U1.29 (PC7); also elsewhere on the board
/AT_~EN: U1.3 (PB2); also elsewhere on the board
/Atmel Controller/AT_AREF: C10.1, U1.32 (AREF)
/Atmel Controller/AT_D0: R17.1, U1.40 (PA0)
/Atmel Controller/AT_D1: R16.1, U1.39 (PA1)
/Atmel Controller/AT_D2: R15.1, U1.38 (PA2)
/Atmel Controller/AT_D3: R14.1, U1.37 (PA3)
/Atmel Controller/AT_D4: R13.1, U1.36 (PA4)
/Atmel Controller/AT_D5: R12.1, U1.35 (PA5)
/Atmel Controller/AT_D6: R11.1, U1.34 (PA6)
/Atmel Controller/AT_D7: R10.1, U1.33 (PA7)
/Atmel Controller/AT_MISO: J3.1, U1.7 (PB6)
/Atmel Controller/AT_MOSI: J3.4, U1.6 (PB5)
/Atmel Controller/AT_SCK: J3.3, U1.8 (PB7)
/Atmel Controller/AT_XTI: C2.1, U1.13 (XTAL1), Y1.2
/Atmel Controller/AT_XTO: C1.1, U1.12 (XTAL2), Y1.1
/Atmel Controller/PD2: J1.4, U1.16 (PD2)
/Atmel Controller/PD3: J1.3, U1.17 (PD3)
/Atmel Controller/PD7: D1.1 (K), U1.21 (PD7)
/Atmel Controller/RXD0: R2.1, U1.14 (PD0)
/Atmel Controller/TXD0: R3.2, U1.15 (PD1)
/Atmel Controller/U_5V: C5.1, J4.3, J5.1
/Atmel Controller/U_RXI: J5.4, R3.1
/Atmel Controller/U_TXO: J5.3, R2.2
/Atmel Controller/~AT_RESET: C3.1, J3.5, R1.2, SW1.2, U1.9 (~RESET)
/CPU_~IRQ: U1.5 (PB4); also elsewhere on the board
/CPU_~NMI: U1.4 (PB3); also elsewhere on the board
/CPU_~RESET: U1.1 (PB0); also elsewhere on the board
/D0: R17.2; also elsewhere on the board
/D1: R16.2; also elsewhere on the board
/D2: R15.2; also elsewhere on the board
/D3: R14.2; also elsewhere on the board
/D4: R13.2; also elsewhere on the board
/D5: R12.2; also elsewhere on the board
/D6: R11.2; also elsewhere on the board
/D7: R10.2; also elsewhere on the board
/PWM_CLK: U1.20 (PD6); also elsewhere on the board
/ROM_SEL: U1.18 (PD4); also elsewhere on the board
/R~W: U1.2 (PB1); also elsewhere on the board
/SCL: J6.3, R18.2, U1.22 (PC0)
/SDA: J6.4, R9.2, U1.23 (PC1)
GND: C1.2, C2.2, C3.2, C5.2, C6.2, C9.2, C10.2, J1.1, J3.6, J5.2, J6.1, SW1.1, U1.11 (GND), U1.31 (GND); also elsewhere on the board
unnamed: D1.2 (A), R5.2
VCC: C6.1, C9.1, J1.2, J3.2, J4.2, J6.2, R1.1, R5.1, R9.1, R18.1, U1.10 (VCC), U1.30 (AVCC); also elsewhere on the board

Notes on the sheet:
ISP Prog
I2C
5V from USB-UART or VIN
Original had PD7 as clk-ff reset
IRQ/NMI swapped from original
Note: can use internal PAx pull-ups (possibly) Maybe change to 680R to use similar resistors to the LEDs
CP2101 UART module
Note: AVRisp recommends 10K to avoid nRESET issues

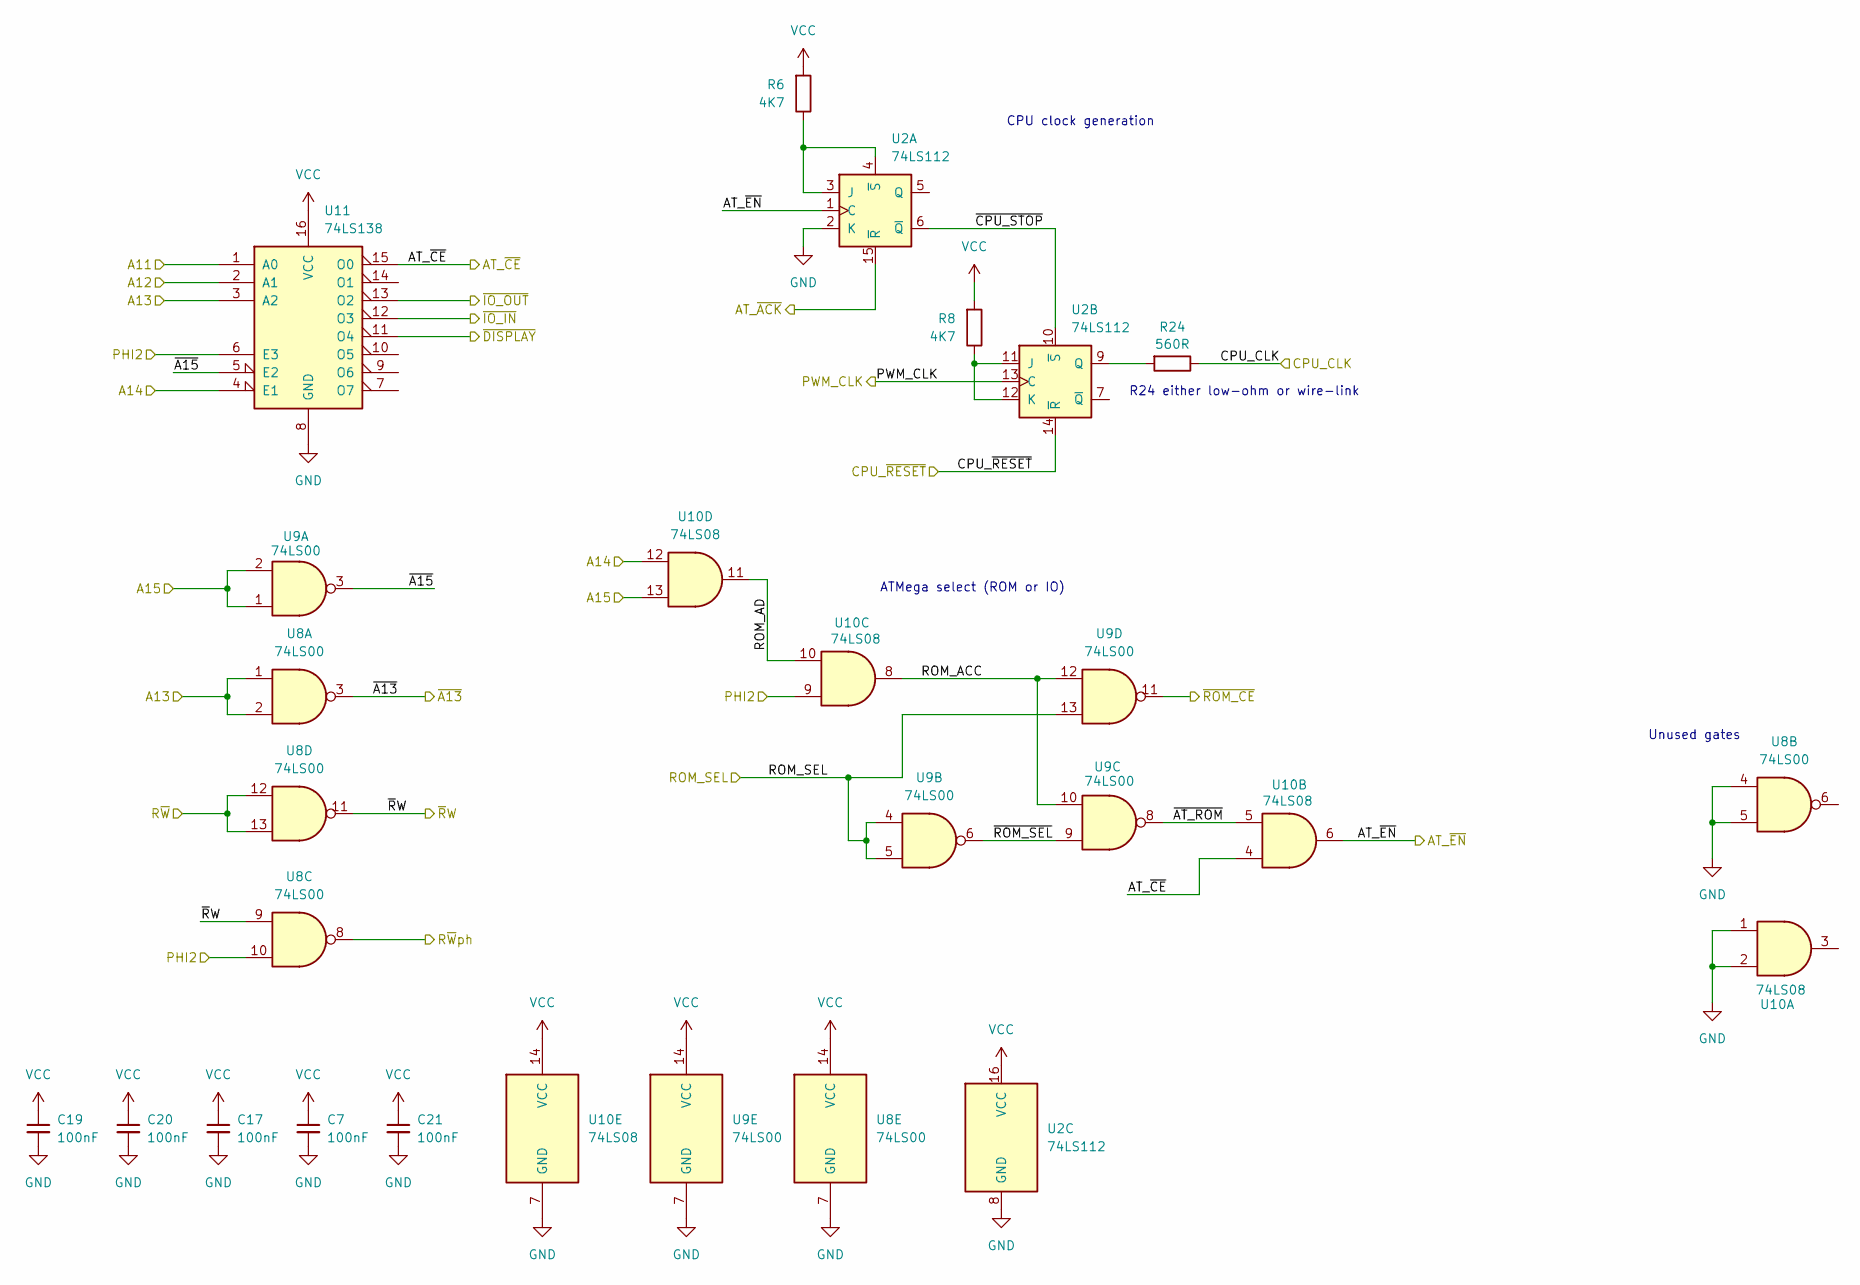
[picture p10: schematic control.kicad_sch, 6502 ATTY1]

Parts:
C7, C17, C19, C20, C21: 100nF; C_Disc_D4.3mm_W1.9mm_P5.00mm
R6, R8: 4K7; R_Axial_DIN0207_L6.3mm_D2.5mm_P10.16mm_Horizontal
R24: 560R; R_Axial_DIN0207_L6.3mm_D2.5mm_P10.16mm_Horizontal
U2: 74LS112; DIP-16_W7.62mm
U8, U9: 74LS00; DIP-14_W7.62mm
U10: 74LS08; DIP-14_W7.62mm
U11: 74LS138; DIP-16_W7.62mm

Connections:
/A11: U11.1 (A0); also elsewhere on the board
/A12: U11.2 (A1); also elsewhere on the board
/A13: U8.1, U8.2, U11.3 (A2); also elsewhere on the board
/A14: U10.12, U11.4 (E1); also elsewhere on the board
/A15: U9.1, U9.2, U10.13; also elsewhere on the board
/AT_ACK: U2.15 (~R); also elsewhere on the board
/AT_~CE: U10.4, U11.15 (O0); also elsewhere on the board
/AT_~EN: U2.1 (C), U10.6; also elsewhere on the board
/CPU_CLK: R24.1; also elsewhere on the board
/CPU_~RESET: U2.14 (~R); also elsewhere on the board
/PHI2: U8.10, U10.9, U11.6 (E3); also elsewhere on the board
/PWM_CLK: U2.13 (C); also elsewhere on the board
/ROM_SEL: U9.4, U9.5, U9.13; also elsewhere on the board
/R~W: U8.12, U8.13; also elsewhere on the board
/R~Wph: U8.8; also elsewhere on the board
/control/ROM_ACC: U9.10, U9.12, U10.8
/control/ROM_AD: U10.10, U10.11
/control/~A15: U9.3, U11.5 (E2)
/control/~AT_ROM: U9.8, U10.5
/control/~CPU_STOP: U2.6 (~Q), U2.10 (~S)
/control/~ROM_SEL: U9.6, U9.9
/~A13: U8.3; also elsewhere on the board
/~DISPLAY: U11.11 (O4); also elsewhere on the board
/~IO_IN: U11.12 (O3); also elsewhere on the board
/~IO_OUT: U11.13 (O2); also elsewhere on the board
/~ROM_CE: U9.11; also elsewhere on the board
/~RW: U8.9, U8.11; also elsewhere on the board
GND: C7.2, C17.2, C19.2, C20.2, C21.2, U2.2 (K), U2.8 (GND), U8.4, U8.5, U8.7 (GND), U9.7 (GND), U10.1, U10.2, U10.7 (GND), U11.8 (GND); also elsewhere on the board
unnamed: R6.1, U2.3 (J), U2.4 (~S)
unnamed: R8.1, U2.11 (J), U2.12 (K)
unnamed: R24.2, U2.9 (Q)
VCC: C7.1, C17.1, C19.1, C20.1, C21.1, R6.2, R8.2, U2.16 (VCC), U8.14 (VCC), U9.14 (VCC), U10.14 (VCC), U11.16 (VCC); also elsewhere on the board

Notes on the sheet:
R24 either low-ohm or wire-link
ATMega select (ROM or IO)
Unused gates
CPU clock generation

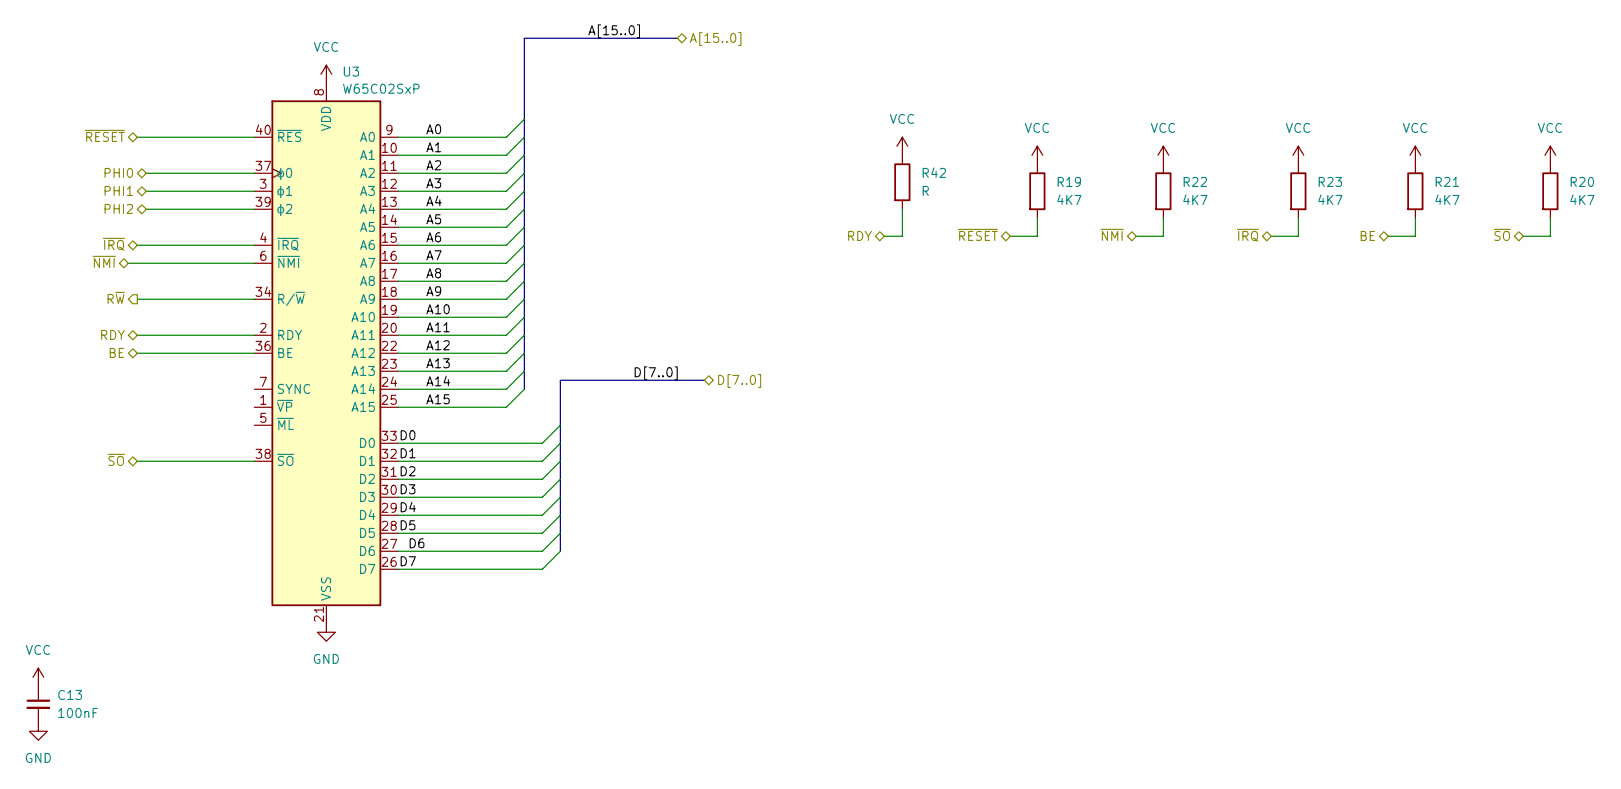
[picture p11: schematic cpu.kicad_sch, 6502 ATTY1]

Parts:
C13: 100nF; C_Disc_D4.3mm_W1.9mm_P5.00mm
R19, R20, R21, R22, R23: 4K7; R_Axial_DIN0207_L6.3mm_D2.5mm_P10.16mm_Horizontal
R42: R; R_Axial_DIN0207_L6.3mm_D2.5mm_P10.16mm_Horizontal
U3: W65C02SxP; DIP-40_W15.24mm

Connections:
/A0: U3.9 (A0); also elsewhere on the board
/A1: U3.10 (A1); also elsewhere on the board
/A2: U3.11 (A2); also elsewhere on the board
/A3: U3.12 (A3); also elsewhere on the board
/A4: U3.13 (A4); also elsewhere on the board
/A5: U3.14 (A5); also elsewhere on the board
/A6: U3.15 (A6); also elsewhere on the board
/A7: U3.16 (A7); also elsewhere on the board
/A8: U3.17 (A8); also elsewhere on the board
/A9: U3.18 (A9); also elsewhere on the board
/A10: U3.19 (A10); also elsewhere on the board
/A11: U3.20 (A11); also elsewhere on the board
/A12: U3.22 (A12); also elsewhere on the board
/A13: U3.23 (A13); also elsewhere on the board
/A14: U3.24 (A14); also elsewhere on the board
/A15: U3.25 (A15); also elsewhere on the board
/CPU_CLK: U3.37 (ϕ0); also elsewhere on the board
/CPU_~IRQ: R23.2, U3.4 (~IRQ); also elsewhere on the board
/CPU_~NMI: R22.2, U3.6 (~NMI); also elsewhere on the board
/CPU_~RESET: R19.2, U3.40 (~RES); also elsewhere on the board
/D0: U3.33 (D0); also elsewhere on the board
/D1: U3.32 (D1); also elsewhere on the board
/D2: U3.31 (D2); also elsewhere on the board
/D3: U3.30 (D3); also elsewhere on the board
/D4: U3.29 (D4); also elsewhere on the board
/D5: U3.28 (D5); also elsewhere on the board
/D6: U3.27 (D6); also elsewhere on the board
/D7: U3.26 (D7); also elsewhere on the board
/PHI2O: U3.39 (ϕ2); also elsewhere on the board
/R~W: U3.34 (R/~W); also elsewhere on the board
/cpu/BE: R21.2, U3.36 (BE)
/cpu/PHI1: U3.3 (ϕ1)
/cpu/RDY: R42.2, U3.2 (RDY)
/cpu/~SO: R20.2, U3.38 (~SO)
GND: C13.2, U3.21 (VSS); also elsewhere on the board
VCC: C13.1, R19.1, R20.1, R21.1, R22.1, R23.1, R42.1, U3.8 (VDD); also elsewhere on the board

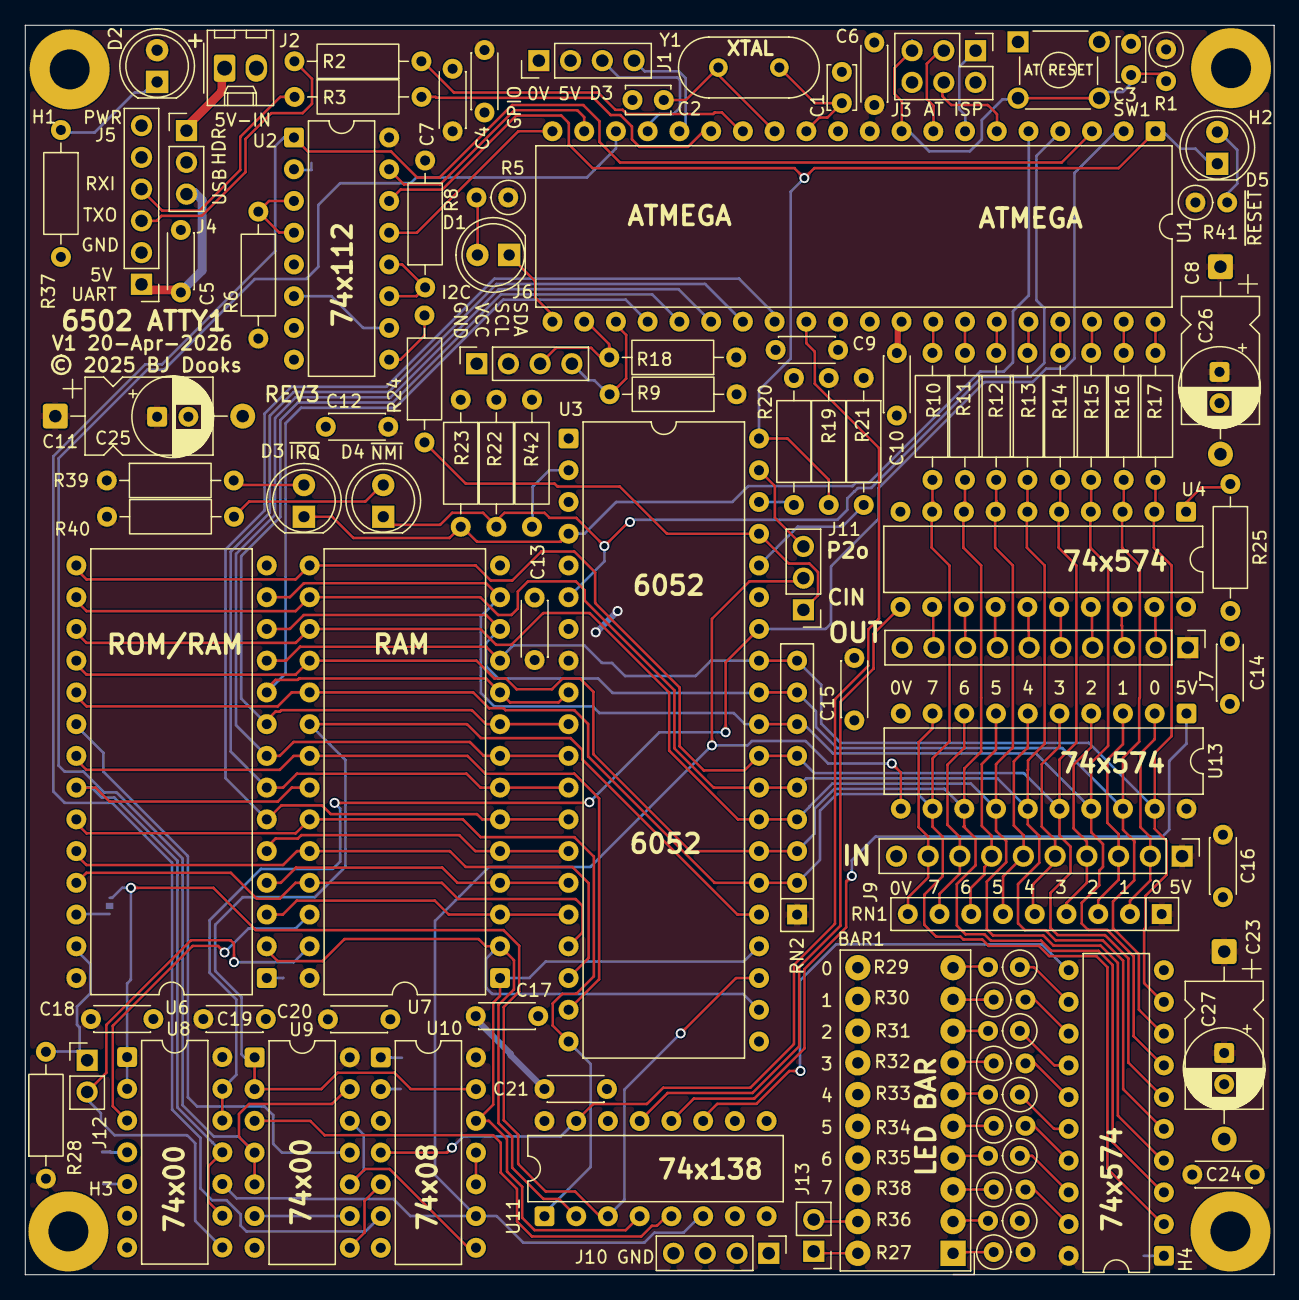
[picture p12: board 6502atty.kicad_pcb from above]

Board: 2 copper layers, 100.0 x 100.0 mm, 104 parts (1 on the bottom side), 127 nets.

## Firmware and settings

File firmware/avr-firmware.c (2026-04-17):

#include <avr/io.h>
#include <avr/power.h>
#include <avr/interrupt.h>
#include <avr/wdt.h>
#include <util/delay.h>
#include <util/twi.h>
#include <avr/pgmspace.h>

#include <stdio.h>
#include <string.h>
#include <stdarg.h>
#include <stdint.h>
#include <stdbool.h>

void pf(const char *msg, ...);
  
#include "gpio.h"
#include "pins.h"
#include "pin_defaults.h"

#include "git-rev.h"
#include "build-info.h"

const char build_info[] = "BUILD: " BUILD_TYPE "\n" \
  "BUILD-BY: " BUILD_BY "\n" \
  "GIT-VER: " GIT_VERSION "\n" \
  "GIT-SHA: " GIT_HEAD "\n";

static void init_pwm(void)
{
	TCCR2A = (2 << 4) | (1); /* for phase correct pwm */
	TCCR2B = (1) | (1 << 3);	/* no prescaler, phase correct */

	/* note, we don't really need to be outputing a square pwm as
	 * the second flip-flop in the timing circuit is going to make
	 * the result square.
	 */

	/* OCR2a = 6, OCR2b = 2 => gives a cpu-freq around 768kHz
	 * OCR2a = 4, OCR2b = 2 => gives a cpu-freq around 1.14MHz
	 * OCR2a = 3, OCR2b = 1 => gives a cpu-freq around 1.53MHz
	 * OCR2a = 2, OCR2b = 1 => gives a cpu-freq around 2.3MHz
	 */
	OCR2A = 4;
	OCR2B = 1;
}

static unsigned char rom[32] = {
	/* download code helper */
	0xA9, 0x00,		/* LDA #0x00 */
	0x8D, 0x00, 0x00,	/* STA 0x0000 */
	0x90, 0xF9,		/* BCC start */
	0x4C, 0xCD, 0xAB,	/* JMP 0xABCD */
};

static unsigned char halted = 0;

ISR(TIMER1_COMPA_vect)
{
	if (!halted)
		toggle_pin(PIN_AT_LED);
}

/* set the clock divider post initialisation. The fuses only allow /1 or /8
 * and if we're using the 18.432 MHz option then the /2 option is probably
 * the best.
 */
static void init_clock(void)
{
	if (F_CPU == F_XTAL) {
		CLKPR = 0 | (1 << CLKPCE);
		CLKPR = 0;
	} else if (F_CPU == (F_XTAL / 2)) {
		CLKPR = 0 | (1 << CLKPCE);
		CLKPR = 1;
	} else {
		extern void __bad_crystal(void);
		__bad_crystal();	/* default to compiler link error */
	}

	/* wait for clock change to take place */
	while (CLKPR & (1 << CLKPCE)) { }
}

#define USART_BAUDRATE	115200
#define BAUD_PRESCALE	(((F_CPU / (USART_BAUDRATE * 16UL))) - 1)

 void init_uart(void)
{
	UBRR0L = BAUD_PRESCALE;
	UBRR0H = (BAUD_PRESCALE >> 8);

	UCSR0C = (1<<UCSZ00)|(1<<UCSZ01);		/* set to 8n1 */
	UCSR0B = (1 << TXEN0)| (1 << RXEN0);	/* enable rx/tx */
	//UCSR0B |= (1 << RXCIE) | (1 << TXCIE) | (1 << UDRIE);	/* irq enable */
}


/* uart handling routines */
static unsigned uart_hasbyte(void)
{
	return (UCSR0A & (1 << RXC0));
}

static uint8_t uart_getbyte(void)
{
	return UDR0;
}

static void uart_putbyte(uint8_t byte)
{
	while( (UCSR0A & (1<<UDRE0)) == 0) { }	/* wait for uart empty */
	UDR0 = byte;
}

static void uart_putc(uint8_t byte)
{
	if (byte == '\n')
		uart_putbyte('\r');
	uart_putbyte(byte);
}

/* simple printf-like routine with small buffer */
void pf(const char *msg, ...)
{
	va_list va;
	char buff[40];
	int off, len;

	va_start(va, msg);
	len = vsnprintf(buff, sizeof(buff), msg, va);
	va_end(va);

	for (off = 0; off < len; off++)
		uart_putc(buff[off]);
}

/* hand assembled 6502 for doing stuff */

const unsigned char download_code[] PROGMEM = {
	/*

*=$c000
LDX #$00
loop STX $801E
INX
BCC loop
BRK
.END
	*/
	0x18,
	0xa2, 0x00,
	0x8e, 0x1e, 0x80,
	0xe8,
	0x90, 0xfa,
	0x00,
};


static const unsigned char ramtest_code_read[] PROGMEM = {
/*
*=$c000
//CLC
loop
LDX $0123
STX $801F
BCC loop
.END
*/
	//0x18,
	0xae, 0x23, 0x01,
	0x8e, 0x1f, 0x80,
	0x90, 0xf8,
};

#if 0
const unsigned char *download_ptr = download_code;
unsigned download = sizeof(download_code);
#endif

#if 0
#include "target_asm/test_null.th"

const unsigned char *download_ptr = test_null_bin;
unsigned download = sizeof(test_null_bin);
#endif

#if 0
#include "target_asm/test_inc.th"

const unsigned char *download_ptr = test_inc_bin;
unsigned download = sizeof(test_inc_bin);
#endif

#if 1
#include "target_asm/test_str.th"

const unsigned char *download_ptr = test_str_bin;
unsigned download = sizeof(test_str_bin);
#endif

unsigned download_to = 0x800;

static const unsigned ram_sz = 8 * 1024;
static unsigned ram_test_ptr = 0x0000;
static unsigned ram_test = 0;

static unsigned ram_test_pattern(unsigned addr)
{
	// really simple ram test pattern
	return (addr ^ (addr >> 8));
}

static void halt(void)
{
	pf("HALT\n");
	set_pin(PIN_6502_nRESET, 0);
	halted = 1;
	PORTD &= ~(1 << 7);		
}

static void ram_test_isr_code(unsigned addr)
{
	unsigned int ptr;

	/* assume addr has been checked and is 1 */

	if (ram_test_ptr >= ram_sz) {
		ram_test++;
		ram_test_ptr = 0x0;

		switch (ram_test) {
		case 2:
			pf("RAM test - patterns written\n");

			for (ptr = 0x00; ptr < 0x10; ptr++)
				rom[ptr] = pgm_read_byte(ramtest_code_read + ptr);

			PORTA = rom[1];
			break;
		case 3:
			pf("RAM test done\n");
			halt();
			/* done */
		}
	} else if (ram_test_ptr == 0x00) {
		pf("RAM test - pass %d\n", ram_test);
	} else if ((ram_test_ptr & 0xff) == 0) {
		pf(".");
	}

	switch (ram_test) {
	case 1:
		rom[1] = ram_test_pattern(ram_test_ptr);
		rom[3] = ram_test_ptr & 0xff;
		rom[4] = ram_test_ptr >> 8;
		ram_test_ptr++;
		break;
	case 2:
		rom[1] = ram_test_ptr & 0xff;
		rom[2] = ram_test_ptr >> 8;
		break;
	}

}

static unsigned dump_mem;
static unsigned count = 0;

// seem to be seeing double execution of the CLC instruction at 0x00
// but with two cycles, the first is addr, adn then with addr+1

/* update the download code ram when addr+0x0 is read so that the
 * download data is there and if the download is finished we continue
 * on past the BCC loop
 */
static inline void update_download_state(void)
{
	rom[1] = pgm_read_byte(download_ptr);
	rom[3] = download_to & 0xff;
	rom[4] = download_to >> 8;
	pf("DL %04x %02x (C=%d)\n", download_to, rom[1], count);

	download_to++;
	download_ptr++;
	download--;

	if (download == 0) {
		pf("Download done\n");
		rom[5] = 0xb0;  /* change BCC to BCS */
	}
}

/* device is reading from emulated rom, so we need to return a value on the
 * data lines depending on the address
 */
static inline void handle_rom_read(unsigned addr)
{
	PORTA = rom[addr];

	if (addr == 0x1e && false) {
		unsigned ptr;
		pf("BRK!\n");

		for (ptr = 0x00; ptr < 0x10; ptr++)
			rom[ptr] = pgm_read_byte(ramtest_code_read + ptr);

		PORTA = rom[addr];
		download_to = 0x1fc;
		dump_mem  = 1;
		download = 0;
		ram_test = 0;
		rom[5] = 0x1d;  // change where memory is written to
	}

	if (download) {
		if (addr == 0)
			update_download_state();
	} else if (ram_test) {
		if (addr == 0)
			ram_test_isr_code(addr);

	} else if (dump_mem) {
		if (addr == 0) {
			pf("DBG %04x = ", download_to);
			rom[1] = download_to & 0xff;
			rom[2] = download_to >> 8;
			download_to++;
			if (download_to == 0x200)
				download_to = 0x800;
			if (download_to > 0x810) {
				halt();
			}
		}

	}

	if (0) {
		pf("RR: A=%02x => %02x\n", addr, PORTA);
	}
}

/* device write handler
 *
 * register map is
 *
 * 0x1B		NULL register (IO cycle testing)
 * 0x1C		Write data byte written to serial output
 * 0x1D		Print hex representation of data written
 * 0x1E		Debug print port
 * 0x1F		Internal use (currently part of RAM test)
 */
static void handle_dev_write(unsigned addr, unsigned data)
{
	unsigned tmp;

	switch (addr) {
	case 0x1b:
		/* for now a quick test */
		break;
	case 0x1c:
		uart_putbyte(data);
		break;
	case 0x1d:
		pf("%02x\n", data);
		break;
	case 0x1e:
		pf("DBG %02x\n", data);
		break;

	case 0x1f:
		tmp =  ram_test_pattern(ram_test_ptr) & 0xff;
		if (data == tmp) {
			// good, ignore //
		} else {
			pf("RT %04x -> got %02x want %02x, diff %02x\n",
			   ram_test_ptr, data, tmp, data ^ tmp);
			_delay_ms(100);
		}
		ram_test_ptr++;
		break;

	default:
		if (1)
			pf("DW unhandled %02x %02x\n", addr, data);
	}
}

ISR(INT2_vect)
{
	unsigned portc = PINC;
	unsigned addr = (portc >> 2) & 0x1f;
	unsigned read = PINB & (1 << 1);
	unsigned is_rom = (portc & (1 << 7));

	/* PB0 is high for read
	 * PC7 being 0 means selelected as IO device */

	if (read) {
		if (!is_rom) {
			pf("RD %02x = %02x C=%u\n", addr, rom[addr], count);
		} else {
			if (0 || (addr >= 0x1e) || dump_mem)
				pf("RD %02x = %02x C=%u\n", addr, rom[addr], count);

			handle_rom_read(addr);
		}
	} else {
		unsigned data;

		/* handle write to device */

		DDRA = 0x00;
		_delay_us(1);
		data = PINA;
		DDRA = 0xff;

		if (0)
			pf("WR %02x %02x\n", addr, data);

		if (!is_rom) {
			handle_dev_write(addr, data);
		} else {
			pf("WR %02x %02x\n", addr, data);
		}
	}

	/* pulse ack pin to let the 6502 continue */
	set_pin(PIN_AT_ACK, 0);
	set_pin(PIN_AT_ACK, 1);

	count++;
	if (count > 128 && false)
		halt();
}

int main(void)
{

	cli();
	wdt_disable();

	count = 0;

	/* initialise our virtual ram/rom */
	rom[0xFC & 0x1f] = 0x00;
	rom[0xFD & 0x1f] = 0xC0;  // set "rom" as reset vector
	rom[0xFE & 0x1f] = 0x00;
	rom[0xFF & 0x1f] = 0xC0;  // set "rom" as break vector
	rom[0xFE & 0x1f] = 0x18;
	rom[0xFF & 0x1f] = 0xC0;  // set "rom" as nmi vector

	init_gpio();
	init_clock();
	init_pwm();
	init_uart();

	sei();

	init_uart();
	if (1) {
	  pf("6502Atty (" GIT_VERSION ")\n");
	}
	
	/* prototype needs to release master reset */
	_delay_ms(100);
#ifdef PIN_MAIN_RESET
	set_pin(PIN_MAIN_RESET, 1);
#endif

	/* enable interrupts */

	EICRA = (1 << ISC21) | (0 << ISC20);
	EIMSK = (1 << 2);

#if 1
	/* timer to toggle leds for testing */

	TCCR1B |= (1 << WGM12); // Configure timer 1 for CTC mode
        OCR1A = 1000000000/(F_CPU/256);        // Set CTC compare value to 1Hz
        TCCR1B |= (1 << CS12);  // Start timer at Fcpu/256

        TIMSK1 = (1 << OCIE1A);
#endif	

	pf("\nstarting 6502..\n");

	/* pulse ack pin to reset the nCPU_STOP signal */
	set_pin(PIN_AT_ACK, 0);
	set_pin(PIN_AT_ACK, 1);

	if (download) {
		rom[8] = download_to & 0xff;
		rom[9] = download_to >> 8;
	}

	if (false) {
		/* we can get around 2.0MHz output from this with around
		 * 55-45% high low */
		pf("Test pattern on LED\n");
		while (true) {
			set_pin(PIN_AT_LED, 0);
			set_pin(PIN_AT_LED, 1);
		}
	}

	_delay_ms(100);
	pf("GO\n");

	set_pin(PIN_6502_nRESET, 1);	/* release 6502 reset */
	while (1) { }
}

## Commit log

2026-03-25 pcb: move around stuff to make pcb smaller
    [6502atty.kicad_pcb, 6502atty.kicad_sch, atmega.kicad_sch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]
2026-03-25 docs: add new pcb view
2026-03-25 pcb: run production output
    [6502atty.kicad_pcb, bom.csv, designators.csv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]
2026-03-25 pcb: minor schematic updates
    [6502atty.kicad_pcb, control.kicad_sch]
2026-03-25 pcb: minor routing fixes, add rjek's bee
    [6502atty.kicad_pcb]
2026-03-25 pcb: silkscreen updates, minor routing updates
    [6502atty.kicad_pcb, control.kicad_sch]
2026-03-25 v1_r2 production data
    [6502atty.kicad_pcb, bom.csv, designators.csv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]
2026-03-26 pcb: fix value of RN1
    also accidentally pushed release2 data
    [bom.csv, designators.csv, io.kicad_sch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]
2026-04-02 start of rev3, reduce x-size, leds consistent
    [6502atty.kicad_pcb, 6502atty.kicad_sch, cpu.kicad_sch]
2026-04-02 missing save commited
    [6502atty.kicad_pcb]
2026-04-02 routing fixes and make teardrops slightly smaller
    [6502atty.kicad_pcb]
2026-04-13 updates for moving pcb stuff around
    [6502atty.kicad_pcb, 6502atty.kicad_sch]
2026-04-13 more movement/updates
    [6502atty.kicad_pcb]
2026-04-17 kicad: routing and board updates
    [6502atty.kicad_pcb, 6502atty.kicad_sch]
2026-04-17 firmware: add comment about timer, go back to string test
2026-04-17 firmware: make IO 0x1C just call putbyte direct
    no point in getting pf() involved with a very simple print
2026-04-17 firmware: add initial device register map
2026-04-23 remove lock file from kicad
    this file should never have been added to the repo, so remove it
2026-04-23 update to kicad10, v1_r3 release
    [6502atty.kicad_pcb, 6502atty.kicad_sch, atmega.kicad_sch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]
2026-04-23 ignore kicad lock files
2026-04-23 updated to use 74x574 for input, then drc fixes
    [6502atty.kicad_pcb, 6502atty.kicad_sch, io.kicad_sch]
2026-04-24 pcb: updated silkscreen bits
    [6502atty.kicad_pcb]
2026-04-27 kicad: v1_rev3 production
    [6502atty.kicad_pcb, bom.csv, designators.csv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]

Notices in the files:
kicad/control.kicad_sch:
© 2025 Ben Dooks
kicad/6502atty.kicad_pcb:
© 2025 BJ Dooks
